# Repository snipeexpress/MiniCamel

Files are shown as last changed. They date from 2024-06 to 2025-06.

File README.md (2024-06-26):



<br/>

The TinyLlama board, assembled
<br/>

This is an expansion of the TinyLlama v2 board created by Eivind Bohler. It combines aspects of the ITX llama as well but in a 100mm x 100mm form factor.

- A fully-fledged 486/Pentium-class PC in a small form factor
- Integrated Sound Blaster Pro-compatible audio using the crystal CS4237b sound chip
- Onboard fan controller for optional CPU or case fan support
- Hard drive clicker and system LED on-board with breakout header for installing in a custom case.
- Support for external OPL3 module from the ITX llama.
- Integrated PCM5102 module
- S/PDIF port for digital audio output
- Ethernet port for 10/100 ethernet capability
- Relocated ESP8266 module for use as dial-up modem emulator or wireless network connectivity.
- Add a Raspberry Pi Zero 2 for Roland MT&#8209;32 and General MIDI music
- Open-source hardware schematics, board layout and BIOS - build your own!

## Table of Contents
- [Summary](#summary)
- [Project Goals](#project-goals)
- [What's New In Version 2?](#whats-new-in-version-2)
- [Full system specs](#full-system-specs-revision-21)
- [Building](#building)
  * [Sourcing Parts](#sourcing-parts)
  * [Assembly](#assembly)
  * [Programming the CH559](#programming-the-ch559)
  * [Programming the BIOS](#programming-the-bios)
  * [Installing DOS](#installing-dos)
  * [Programming the CS4237B Firmware](#programming-the-cs4237b-firmware)
- [MT-32 / General MIDI](#mt-32--general-midi)
- [WiFi Connectivity](#wifi-connectivity)
- [Wiki](#wiki)
- [Help](#help)
- [Roadmap](#roadmap)
- [Contributing](#contributing)
- [License](#license)
- [Contact](#contact)
- [Acknowledgements](#acknowledgments)

<br/>

## Project Goals
I'm learning how to build these types of boards and decided to use a project I've built in the past and that I'm familiar with as a starting point.
The biggest goal I have for this project is to learn enough to begin designing my own circuits. In this case, I am relying on circuits that already exist
but my hope is that my next project will be a scratch-built device that doesn't require any use of pre-existing projects.

<p>
  TinyLlama
</p>

Both the CH559 and the ESP8266 can be easily re-flashed/programmed in-place.  
Look at [Programming the CH559](#programming-the-ch559) and [Programming the ESP8266][wiki-wifi].

## Full system specs (revision 0.1)
### Hardware
- **86Duino System-on-module**
  * Vortex86EX CPU running at 60-500 MHz
  * 16 KB L1 cache (can be disabled)
  * 128 KB L2 cache
  * 128 MB DDR3 RAM
  * 8 MB programmable flash ROM
- **Vortex86VGA module running off a x1 PCI-e lane**
  * Maximum resolution: 1024x768, 60 Hz
  * 4 MB SRAM
  * [Alternative graphics cards][wiki-alternative-gpus]
- **Crystal CS4237B all-in-one audio chip**
- **12mm PC-speaker**
- **12mm HDD clicker speaker**
- **CR1220 battery for persistent real-time clock**
- **Power and reset buttons**
- **Connectivity**
  * USB-C for power
  * 2 x USB Type-A connectors for HID-compliant keyboard and mice
  * 2 x USB Type-A connectors for storage devices (USB 2.0)
  * MicroSD slot for storage
  * DE-9 RS232 serial port (COM1)
  * 1x RJ45 10/100 Ethernet port
  * Modem or Ethernet/SLIP over WiFi (COM2)
  * Internal fan pin-header (5V only)
  * 3.5mm line-out audio jack
  * S/PDIF jack for digital line out
- **mt32-pi subsystem**
  * 40-pin connector for a Raspberry Pi Zero 2
  * Integrated PCM5102 I²S DAC module
  * Button for toggling between MT32 / General MIDI mode
  * Button for switching between audio ROMs / soundbanks
  * 4-pin I²C connector for an OLED display

### Software
- **[Custom Coreboot/SeaBIOS ROM][bios]**
- **MS-DOS / FreeDOS**

<p>
  TinyLlama BIOS
</p>

## Building
### Sourcing Parts
I will post the BOM after I complete the initial test build to make sure everything is correct.

#### For MT-32/MIDI - optional
- Raspberry Pi Zero 2 W with a microSD card
- An [mt32-pi compatible OLED display][mt32-pi-oled], optional but nice

### Programming the CH559
1. Download the latest firmware binary from this repo, in the `hidman-binary` folder. Alternatively, get the latest source code from the [official repo][hidman] and compile it yourself.
2. Download and install `WCHISPTool_Setup.exe` from [WCH's website][wch]. Unfortunately, this tool only supports Windows. If you're on macOS or Linux, maybe try using virtualization software, or even another computer.
3. Open the `WCHISPTool_CH54x-55x` application.
4. Make sure the MiniCamel is powered off.
5. **Remove** the jumper from the "HID_POWER" pin header on the PCB (to ensure that the computer doesn't backpower the MiniCamel).
6. Connect a USB cable (type A to type A) between one of the HID USB ports on the MiniCamel and the Windows computer.
7. Press and hold the "PRG" button on the bottom side of the MiniCamel until the CH559 device pops up in the WCHISPTool.
8. Select the firmware binary file under _Download File -> Object File1_.
9. Click the "Download" button. Hopefully you'll get a success message in the log section on the right side of the program window.
10. Disconnect the USB cable.
11. **Add** the jumper to the "HID_POWER" pin header on the PCB.
12. Connect a keyboard to one of the HID USB ports. You should be good to go!

### Programming the BIOS
When purchasing the SOM-128-EX module from DMP, its ROM chip comes preinstalled with an Arduino-like bootloader which isn't what we want. Also, the  "crossbar" is configured for using the module with the 86Duino Zero/One boards - meaning its default pin layout is completely different from what we need for the MiniCamel.

Follow these steps to flash the ROM with the MiniCamel BIOS for the first time:
1. Find a USB flash drive, must be minimum 32 MB in size (shouldn't be a problem these days). Note that not all USB drives are bootable. Use a well-known bootable drive. _NB: You have to use a USB stick for this, an SD card won't work since the crossbar is configured to use different pins on the SOM for SD traffic._
2. Do a block-level transfer of the `INITBIOS.IMG` from this repo to the USB drive. Use [Balena Etcher][balena-etcher], or the command line if you know what you're doing (macOS example):
```
$ diskutil list
(Find your USB drive, eg. /dev/disk2)
$ diskutil unmountDisk /dev/disk2
$ sudo dd if=INITBIOS.IMG of=/dev/rdisk2 bs=1m
```
3. Insert the USB flash drive into the MiniCamel and turn it on. It'll hopefully boot into MS-DOS. Then, to flash the ROM:
```
C:\>anybios w initbios.rom
```
...and reboot.  

For subsequent BIOS updates, you can use the ROM's built-in virtual floppy drive available from the boot menu (press F12).  
When booted from this you'll only need a regular USB stick (formatted as FAT16/FAT32) containing the new BIOS file.

### Installing MS-DOS
_A note on selecting the DOS type:  
I've gone with MS-DOS 6.22 for maximum compatibility.  
If you prefer FreeDOS (or another DOS variant), prepare a bootable USB installer disk and use that instead of the built-in virtual floppy._
1. Pick a bootable USB drive or Micro SD card to use as the boot drive - for MS-DOS 6.22 you'll be limited to FAT16 and 2 GB per partition (though you can have several). For FreeDOS with FAT32 you can go all the way up to 2 TB.
2. Insert it, turn on the system, press F12 to bring up the boot menu, and select the virtual floppy drive.
3. Use `fdisk` from the command prompt to partition the SD/USB drive and set it to be `Active`.
4. Restart and again select to boot from the virtual floppy.  
Use `format c: /s /u` to format the drive and copy over system files. Finally use `fdisk /mbr` to make sure the Master Boot Record is correct and the drive should be bootable.
5. Copy over the `DOS` folder from A: to C:.  
You can either do this manually and create `CONFIG.SYS` and `AUTOEXEC.BAT` files to your liking, or more conveniently, just run the `SETUP.BAT` script that'll do this for you. The provided config files lets you choose from a clean boot or a QEMM-based one with XMS, EMS and 631 kB of free conventional memory.

### Programming the CS4237B Firmware
1. Copy the `CS4237B` and `UNISOUND` folders from this GitHub repo over to your SD/USB boot drive and start the system.
2. To program the firmware, run the `RESOURCE.EXE` command below and check that you get the same output:
```
C:\>cd cs4237b
C:\CS4237B>resource /f=0x120 /r=cs4237b.asm /e

Reading data from CS4237B.ASM
Length = 292    Programming EEPROM Block: 1 2    EEPROM programmed

Verifying EEPROM:
Verifying CS4237B.ASM against EEPROM . . .      Verified OKAY
```
3. Make sure the correct `BLASTER` environment variable is set and `UNISOUND.COM` command is called from `AUTOEXEC.BAT`. Note that the 8-bit DMA channel is **1** and the IRQ is **7**:
```
SET BLASTER=A220 I7 D1 P330 T4
C:\UNISOUND\UNISOUND.EXE /V60 /VW60 /VF60 /VL60 /VP60 /VC0 /VM0
```
4. Reboot the system, and you should get the following output:
```
Universal ISA PnP Sound Card Driver for DOS v0.76f. (c) JazeFox 2019-21
-----------------------------------------------------------------------
PnP card found: [CSC7537] CS4237B
BLASTER environment var found! Loading settings...
ADD:220 WSS:534 OPL:388 IRQ:7 DMA:1/1 MPU:330/I9 CTR:120 JOY:200
Initialization done.
Crystal Mixer [VOL:85 WAV:80 FM:80 LIN:0 CD:0 MIC:0]
```
5. Feel free to experiment with the different volume levels, look at the `C:\UNISOUND\UNISOUND.TXT` file for further guidance.
6. Fire up a few games to test that Adlib, SoundBlaster FM and digital sound effects are working properly.

## MT-32 / General MIDI
If you've installed [mt32-pi][mt32-pi] on a Raspberry Pi Zero 2 and connected it to the TinyLlama, it should be ready to go using IO port 330. Use the third button from the left (labeled "SYNTH_SW" on the PCB) to switch between MT-32 and General MIDI mode.  
If you want to play old games that require "MPU-401 Intelligent Mode" (Sierra games, Monkey Island 1, etc), try running [SoftMPU][softmpu]:
```
C:\SOFTMPU\>softmpu /mpu:330 /sb:220 /irq:7
```
If you want to hook up an I²C OLED display to the mt32-pi, there's a pin header on the MiniCamel labeled "I2C_OLED". The order of the pins from 1 to 4 is: GND, VCC, SCL, SDA with pin 1 being the one closest to the 3.5mm audio jack.

## WiFi Connectivity
There's a [section][wiki-wifi] in the wiki dedicated to this, take a look.

## Wiki
For an in-depth discussion of the various components, installation, configuration, etc, take a look at the [wiki][wiki].

## Help
This project is indended for people with a fair bit of hardware- and DOS knowledge. If you have questions or need help, please look at the [wiki][wiki] and [FAQ][wiki-faq] section first.

## License
[GNU General Public License v3.0](LICENSE)

## Acknowledgements

Many thanks to

- [Eivind Bohler] for creating the initial project, helping me troubleshoot my ITX llama and being a HUGE inspiration.
- [Rasteri][rasteri-videos] for creating the WeeCee and Wee86 that got me interested in going down this rabbit hole.
- [The Vogons forum][vogons] for being a great resource and always providing help when needed.
- [86Duino / DMP][86duino] for making a great and affordable system-on-module. (I concur with Eivind on this!)

[tinyllama1]: https://github.com/eivindbohler/tinyllama
[hidman]: https://github.com/rasteri/HIDman
[wiki-alternative-gpus]: https://github.com/eivindbohler/tinyllama2/wiki/alternative-gpus
[bios]: https://github.com/eivindbohler/tinyllama2-bios

[wiki]: https://github.com/eivindbohler/tinyllama2/wiki
[wiki-assembly]: https://github.com/eivindbohler/tinyllama2/wiki/assembly
[wiki-bom]: https://github.com/eivindbohler/tinyllama2/wiki/bom
[wiki-faq]: https://github.com/eivindbohler/tinyllama2/wiki/faq
[wiki-wifi]: https://github.com/eivindbohler/tinyllama2/wiki/wifi-connectivity

[balena-etcher]: https://www.balena.io/etcher
[mt32-pi-oled]: https://github.com/dwhinham/mt32-pi/wiki/LCD-and-OLED-display
[wch]: http://www.wch-ic.com/products/CH559.html

[issues]: https://github.com/eivindbohler/tinyllama2/issues

[rasteri-videos]: https://www.youtube.com/user/TheRasteri/videos
[vogons]: https://www.vogons.org
[86duino]: https://www.86duino.com
[mt32-pi]: https://github.com/dwhinham/mt32-pi
[softmpu]: http://bjt42.github.io/softmpu

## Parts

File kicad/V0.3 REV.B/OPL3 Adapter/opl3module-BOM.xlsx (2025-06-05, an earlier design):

Comment | Designator | Footprint | LCSC
0.1uF | C1,C2,C3,C4,C9,C10,C11,C12,C17,C18,C19,C20,C25,C26,C27,C28,C33,C34,C35,C36,C41,C42,C43,C44 | C_0402_1005Metric | C1525
68pF | C5,C13,C21,C29,C37,C45 | C_0402_1005Metric | C76977
2.7nF | C6,C7,C14,C15,C22,C23,C30,C31,C38,C39,C46,C47 | C_0603_1608Metric | C1625600
10uF | C8,C16,C24,C32,C40,C48 | C_0603_1608Metric | C344022
600Ω@100MHz | FB1,FB2,FB3,FB4,FB5,FB6 | R_0402_1005Metric | C160977
EXT_SYNTH | J1,J2,J3,J4,J5,J6 | P_CONN_02X10 | C492427
33 | R1,R6,R11,R16,R21,R26 | R_0402_1005Metric | C138002
6.8k | R2,R3,R7,R8,R12,R13,R17,R18,R22,R23,R27,R28 | R_0402_1005Metric | C93940
8.2k | R4,R5,R9,R10,R14,R15,R19,R20,R24,R25,R29,R30 | R_0402_1005Metric | C138071
TL074 | U3,U6,U9,U12,U15,U18 | U_TSSOP-14_4.4x5mm_P0.65mm | C6964
14.318MHz | XO1,XO2,XO3,XO4,XO5,XO6 | XO_SMD5032 | C387230

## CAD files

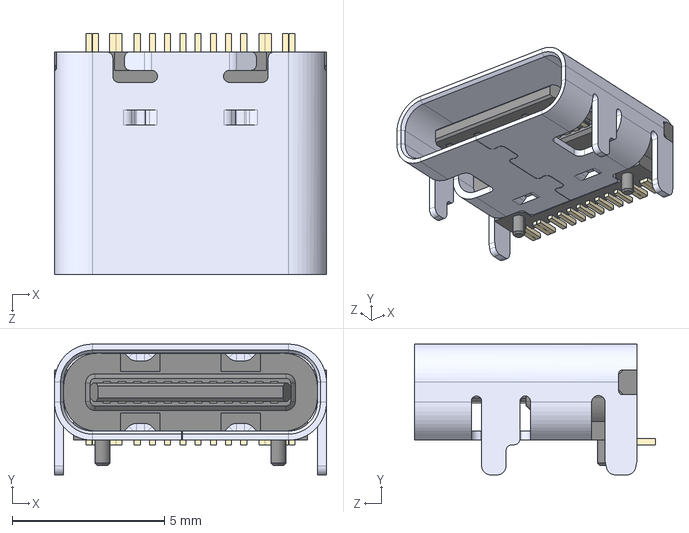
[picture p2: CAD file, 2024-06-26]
3dmodels/TYPE-C-31-M-12--3DModel-STEP-56544.STEP
8.94 x 4.30 x 7.90 mm

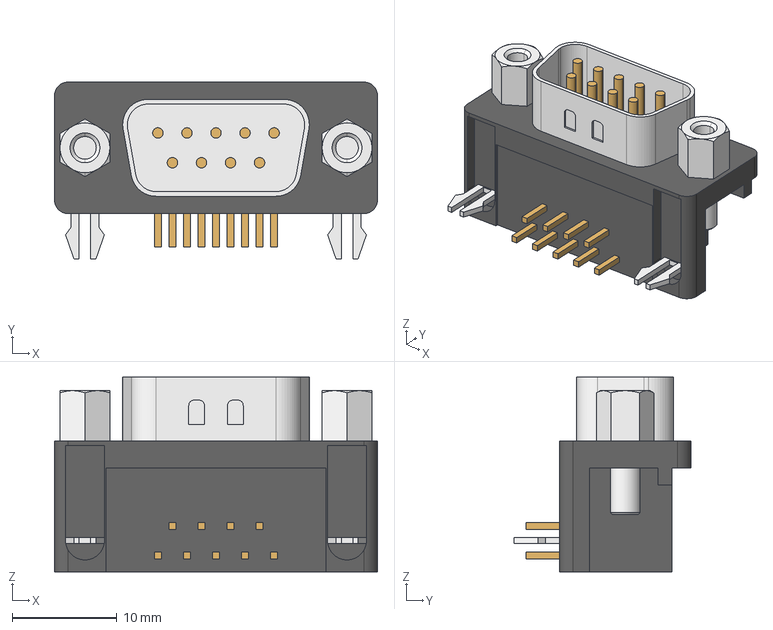
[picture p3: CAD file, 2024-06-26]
kicad/V0.1/3dmodels/connector_a-ds_09_a_kg-t2.step
30.8 x 16.9 x 18.6 mm

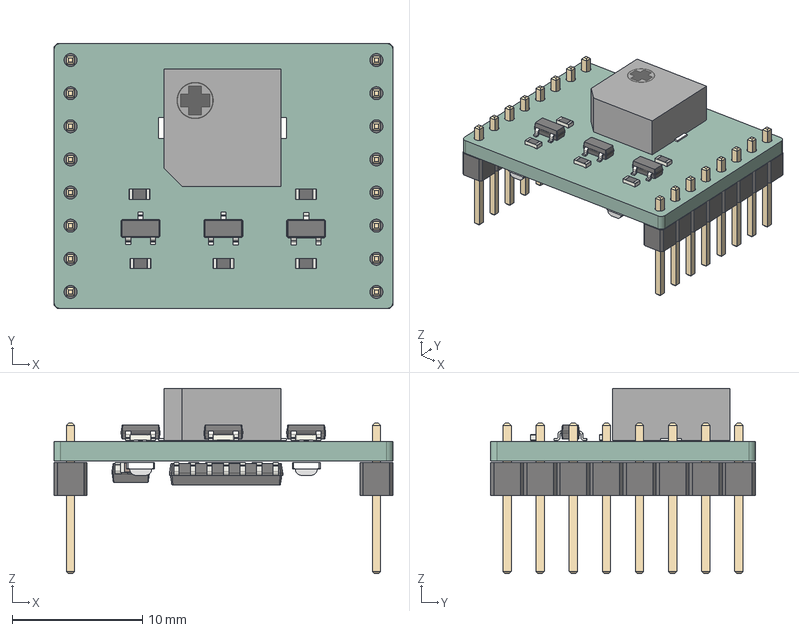
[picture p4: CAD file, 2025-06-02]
kicad/V1.01 REV.B/Riser/PCB_3D_riser.STEP
26.0 x 20.3 x 14.2 mm
R_0603_1608Metric x 7
SMT-0927-S-12-R
SOT-23 x 3
PinHeader_1x08_P2.54mm_Vertical x 2
C_0603_1608Metric x 5
LTST-S220KSKT x 2
SOT-23-5
D_SOD-323F
SOIC-14_3.9x8.7mm_P1.27mm
MiniCamel_riser_PCB

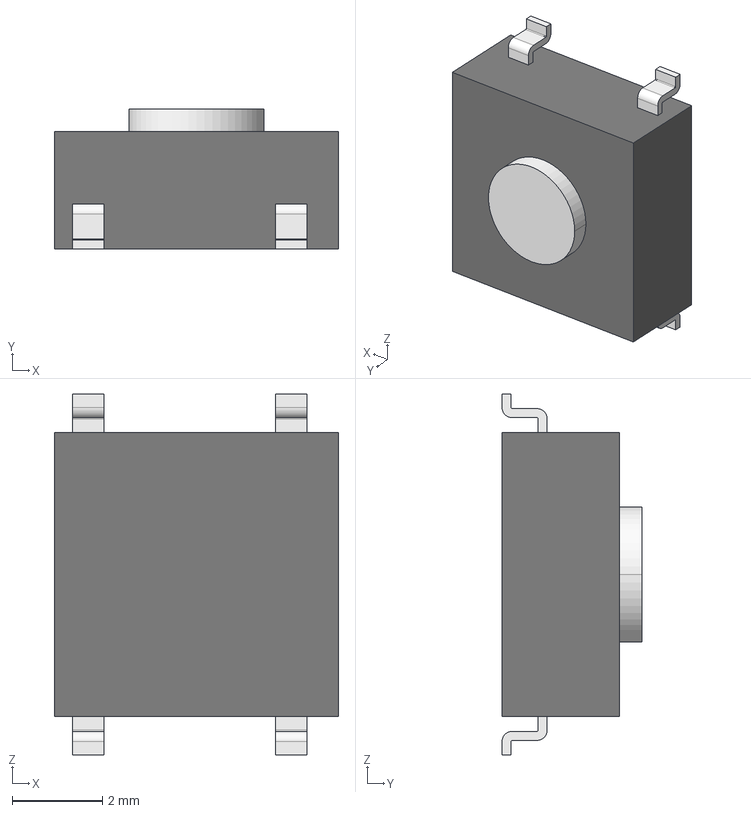
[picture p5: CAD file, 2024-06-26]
3dmodels/b3fs-1000p.stp
6.30 x 3.10 x 8.00 mm

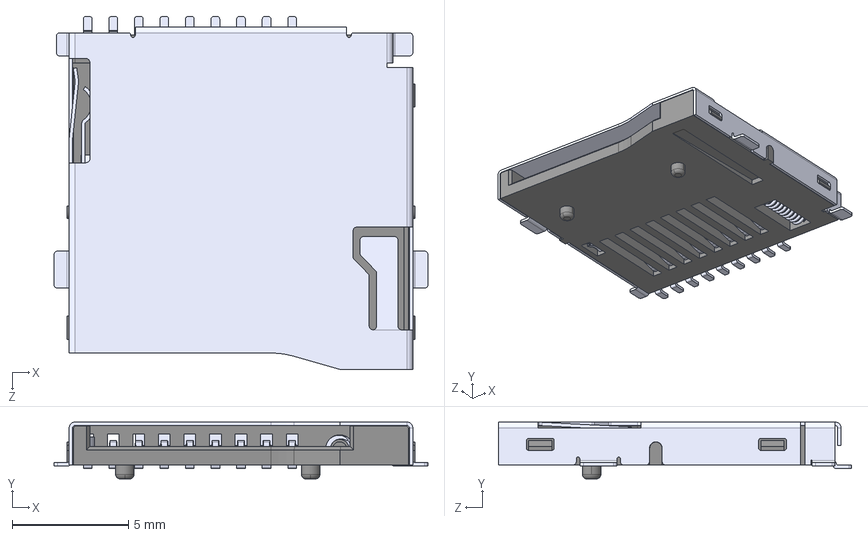
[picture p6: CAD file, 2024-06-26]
kicad/V0.1/3dmodels/TF-01A--3DModel-STEP-56544.STEP
16.1 x 2.45 x 15.2 mm

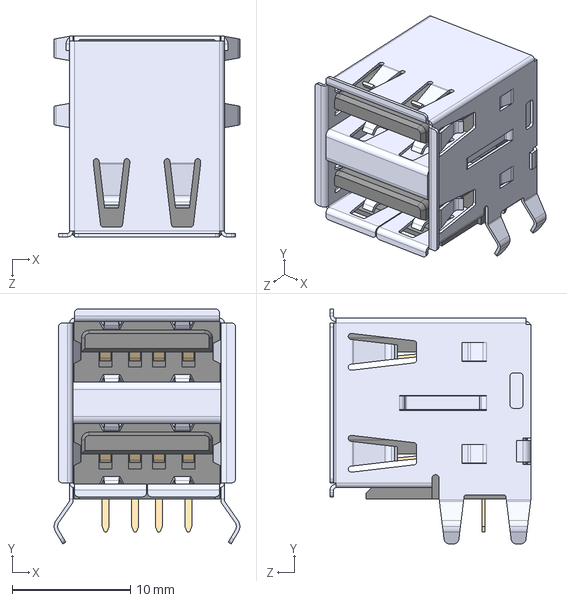
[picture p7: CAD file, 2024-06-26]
3dmodels/USB1035-GF-P-0-B-B--3DModel-STEP-269445.STEP
15.7 x 19.9 x 17.0 mm

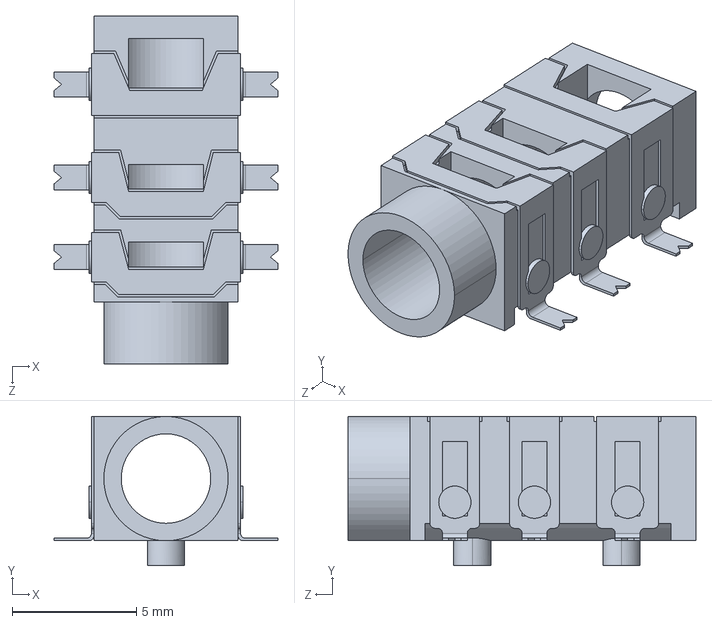
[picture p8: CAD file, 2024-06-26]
kicad/V0.1/3dmodels/JackPJ313D.STEP
9.00 x 6.00 x 14.0 mm

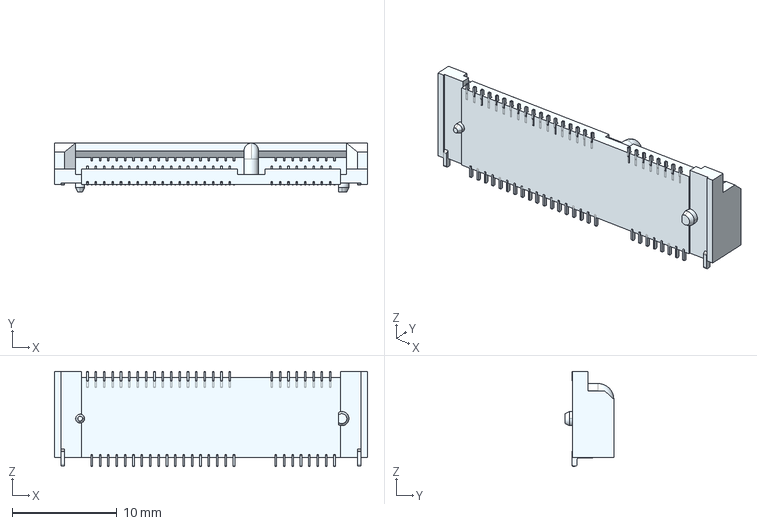
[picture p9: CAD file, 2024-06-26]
3dmodels/2041119-1.stp
29.9 x 4.65 x 9.09 mm

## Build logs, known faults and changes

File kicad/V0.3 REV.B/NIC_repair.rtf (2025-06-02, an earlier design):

Remove c1 and bridge
Replace R2 and R3 with 100nF capacitors
Remove R4 and R5
Cut connection between 4,5 and 7,8 (leave floating)

Change
C45 to 1uF
C47 to 1uF

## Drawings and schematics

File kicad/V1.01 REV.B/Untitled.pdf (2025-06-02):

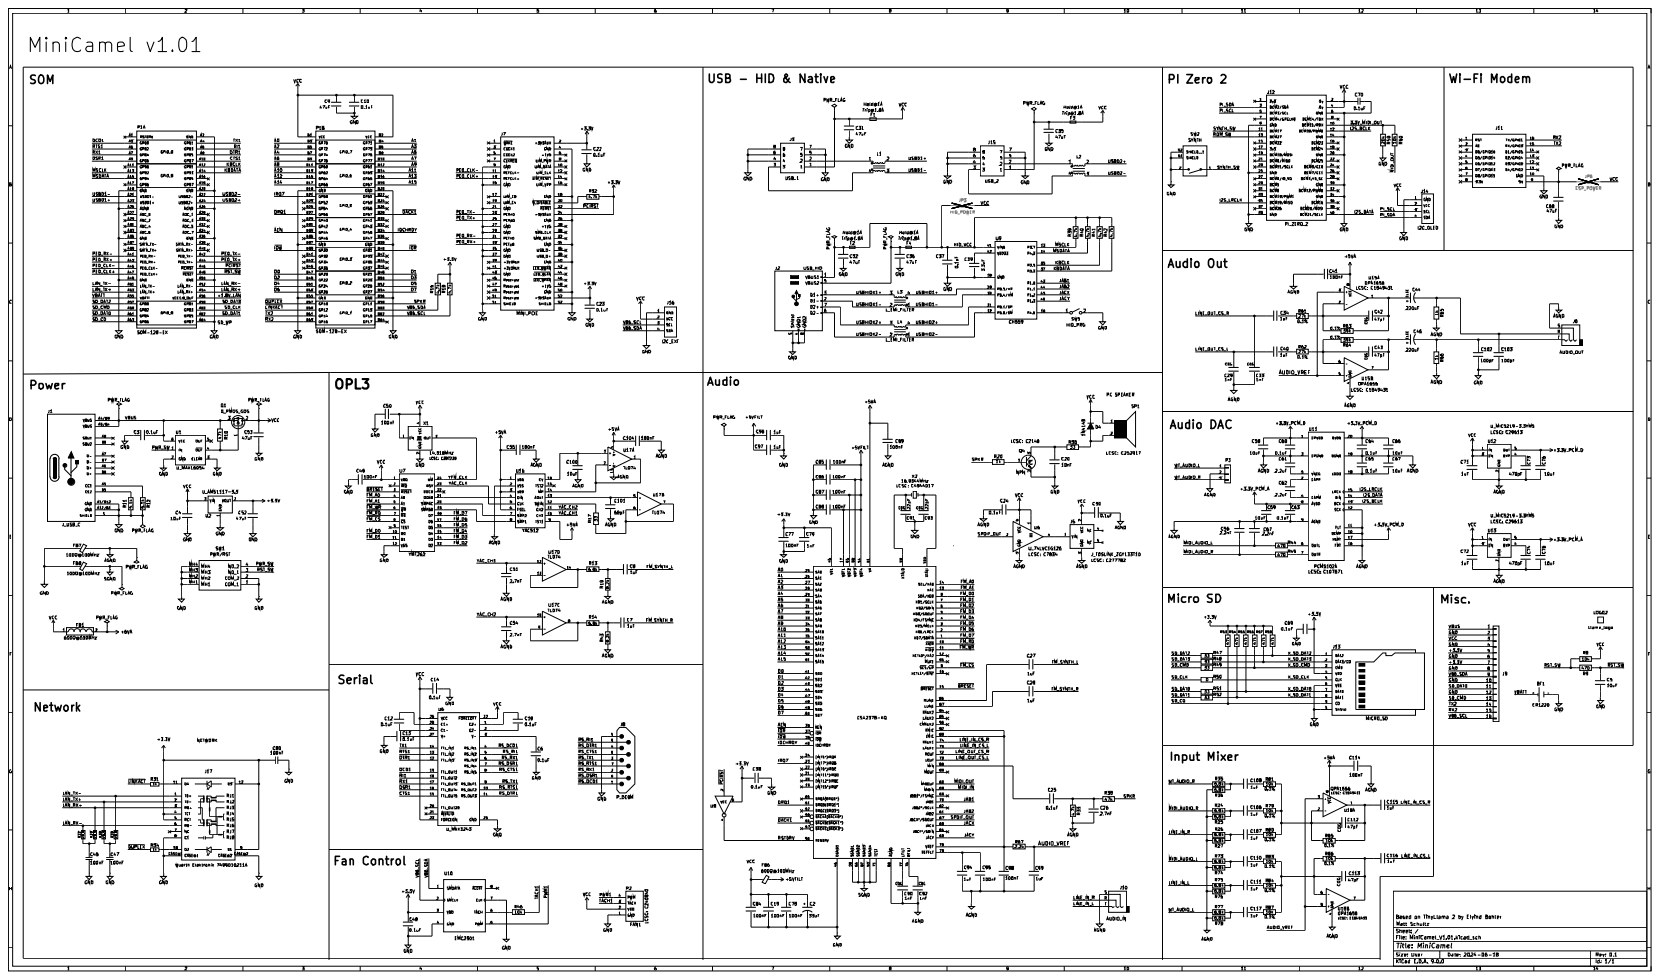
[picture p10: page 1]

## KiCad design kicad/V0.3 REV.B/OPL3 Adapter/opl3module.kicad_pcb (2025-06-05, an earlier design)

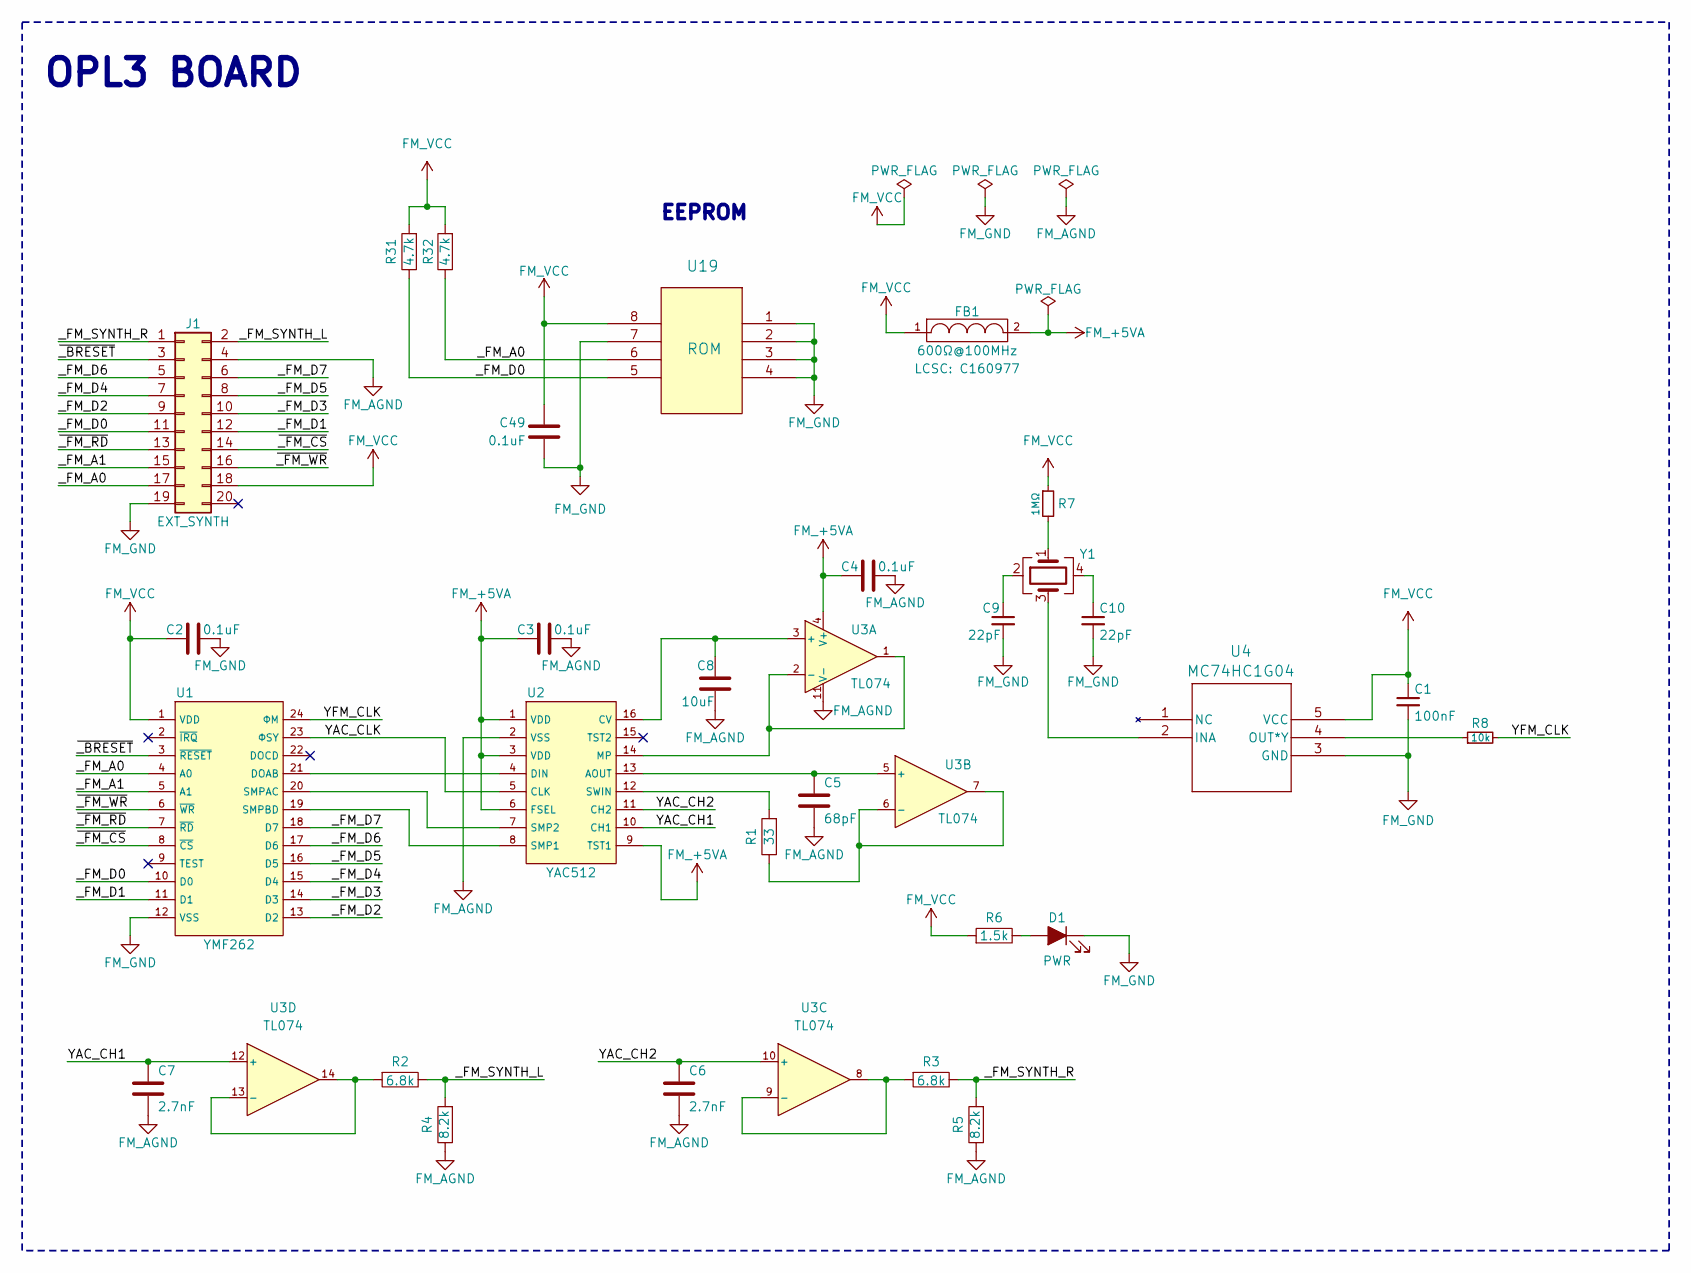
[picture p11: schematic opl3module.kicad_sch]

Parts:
C1: 100nF; C_0402_1005Metric
C2, C3, C4, C49: 0.1uF; C_0402_1005Metric_no_outline
C5: 68pF; C_0402_1005Metric_no_outline
C6, C7: 2.7nF; C_0603_1608Metric_no_outline
C8: 10uF; C_0603_1608Metric_no_outline
C9, C10: 22pF; C_0402_1005Metric
D1: PWR; D_0603_1608Metric; LCSC C130723
FB1: 600Ω@100MHz; R_0402_1005Metric_no_outline; LCSC C160977
J1: EXT_SYNTH; P_CONN_02X10
R1: 33; R_0402_1005Metric_no_outline
R2, R3: 6.8k; R_0402_1005Metric_no_outline
R4, R5: 8.2k; R_0402_1005Metric_no_outline
R6: 1.5k; R_0603_1608Metric_no_outline; LCSC C25117
R7: 1MΩ; R_0603_1608Metric
R8: 10k; R_0603_1608Metric
R31, R32: 4.7k; R_0402_1005Metric_no_outline
U1: YMF262; SOP-24_7.5x15.4mm_P1.27mm
U2: YAC512; SOP-16_4.4x10.4mm_P1.27mm
U3: TL074; SOIC-14_3.9x8.7mm_P1.27mm
U4: MC74HC1G04; SC70-5_ONS
U19: ROM; SOIC8-N_MC_MCH
Y1: Crystal_GND24; Crystal_SMD_5032-4Pin_5.0x3.2mm

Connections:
/YAC_CH1: C7.1, U2.10 (CH1), U3.12 (+)
/YAC_CH2: C6.1, U2.11 (CH2), U3.10 (+)
/YAC_CLK: U1.23 (ΦSY), U2.5 (CLK)
/YFM_CLK: R8.2, U1.24 (ΦM)
/_FM_A0: J1.17, R32.1, U1.4 (A0), U19.6
/_FM_A1: J1.15, U1.5 (A1)
/_FM_D0: J1.11, R31.1, U1.10 (D0), U19.5
/_FM_D1: J1.12, U1.11 (D1)
/_FM_D2: J1.9, U1.13 (D2)
/_FM_D3: J1.10, U1.14 (D3)
/_FM_D4: J1.7, U1.15 (D4)
/_FM_D5: J1.8, U1.16 (D5)
/_FM_D6: J1.5, U1.17 (D6)
/_FM_D7: J1.6, U1.18 (D7)
/_FM_SYNTH_L: J1.2, R2.1, R4.2
/_FM_SYNTH_R: J1.1, R3.1, R5.2
/~_BRESET: J1.3, U1.3 (~RESET)
/~_FM_CS: J1.14, U1.8 (~CS)
/~_FM_RD: J1.13, U1.7 (~RD)
/~_FM_WR: J1.16, U1.6 (~WR)
FM_+5VA: C3.2, C4.2, FB1.2, U2.1 (VDD), U2.3 (VDD), U2.6 (FSEL), U2.9 (TST1), U3.4 (V+)
FM_AGND: C3.1, C4.1, C5.2, C6.2, C7.2, C8.1, J1.4, R4.1, R5.1, U2.2 (VSS), U3.11 (V-)
FM_GND: C1.2, C2.1, C9.2, C10.2, C49.2, D1.1 (K), J1.19, U1.12 (VSS), U4.3 (GND), U19.1, U19.2, U19.3, U19.4, U19.7
FM_VCC: C1.1, C2.2, C49.1, FB1.1, J1.18, R6.2, R7.1, R31.2, R32.2, U1.1 (VDD), U4.5 (VCC), U19.8
unnamed: C9.1, Y1.2
unnamed: C10.1, Y1.4
unnamed: D1.2 (A), R6.1
unnamed: R7.2, Y1.1
unnamed: U1.21 (DOAB), U2.4 (DIN)
unnamed: U1.20 (SMPAC), U2.7 (SMP2)
unnamed: U1.19 (SMPBD), U2.8 (SMP1)
unnamed: C5.1, U2.13 (AOUT), U3.5 (+)
unnamed: C8.2, U2.16 (CV), U3.3 (+)
unnamed: U2.14 (MP), U3.1, U3.2 (-)
unnamed: R1.2, U2.12 (SWIN)
unnamed: R1.1, U3.6 (-), U3.7
unnamed: R3.2, U3.8, U3.9 (-)
unnamed: R2.2, U3.13 (-), U3.14
unnamed: U4.2 (INA), Y1.3
unnamed: R8.1, U4.4 (OUT*Y)

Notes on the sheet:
OPL3 BOARD
EEPROM

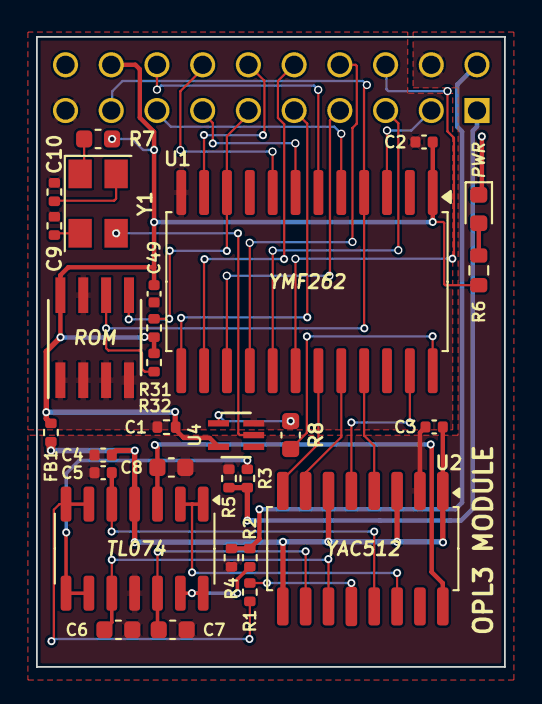
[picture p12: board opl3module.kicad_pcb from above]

Board: 4 copper layers, 26.0 x 35.0 mm, 30 parts (1 on the bottom side), 40 nets.

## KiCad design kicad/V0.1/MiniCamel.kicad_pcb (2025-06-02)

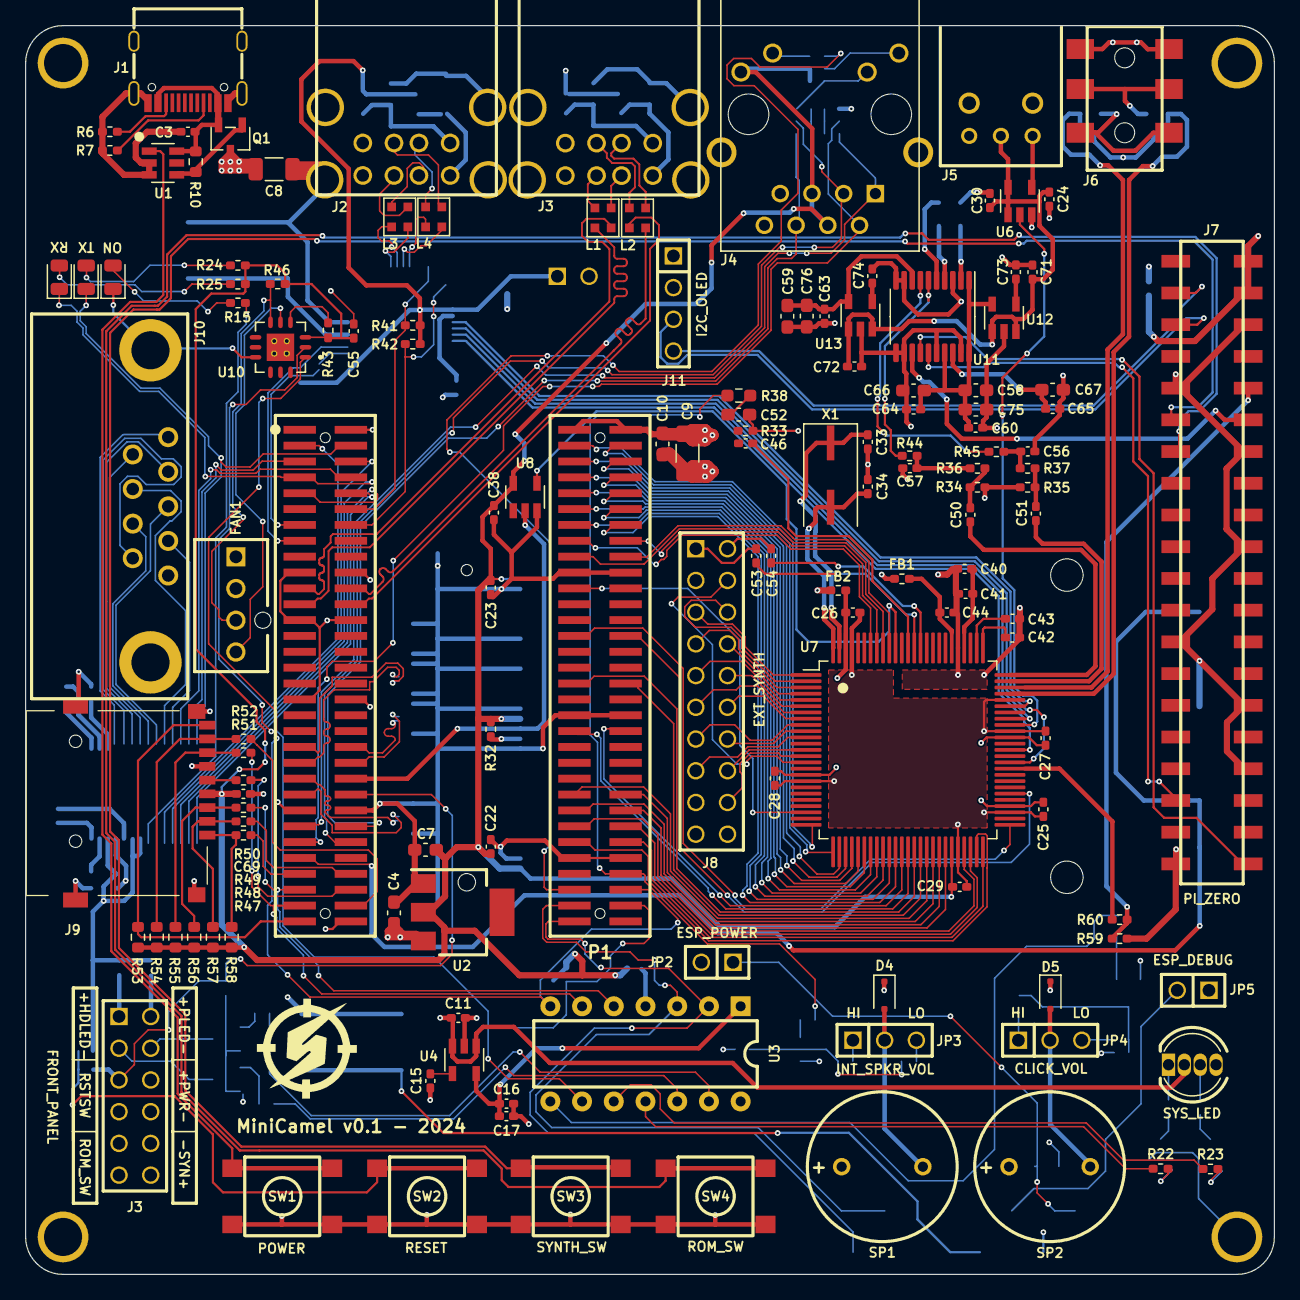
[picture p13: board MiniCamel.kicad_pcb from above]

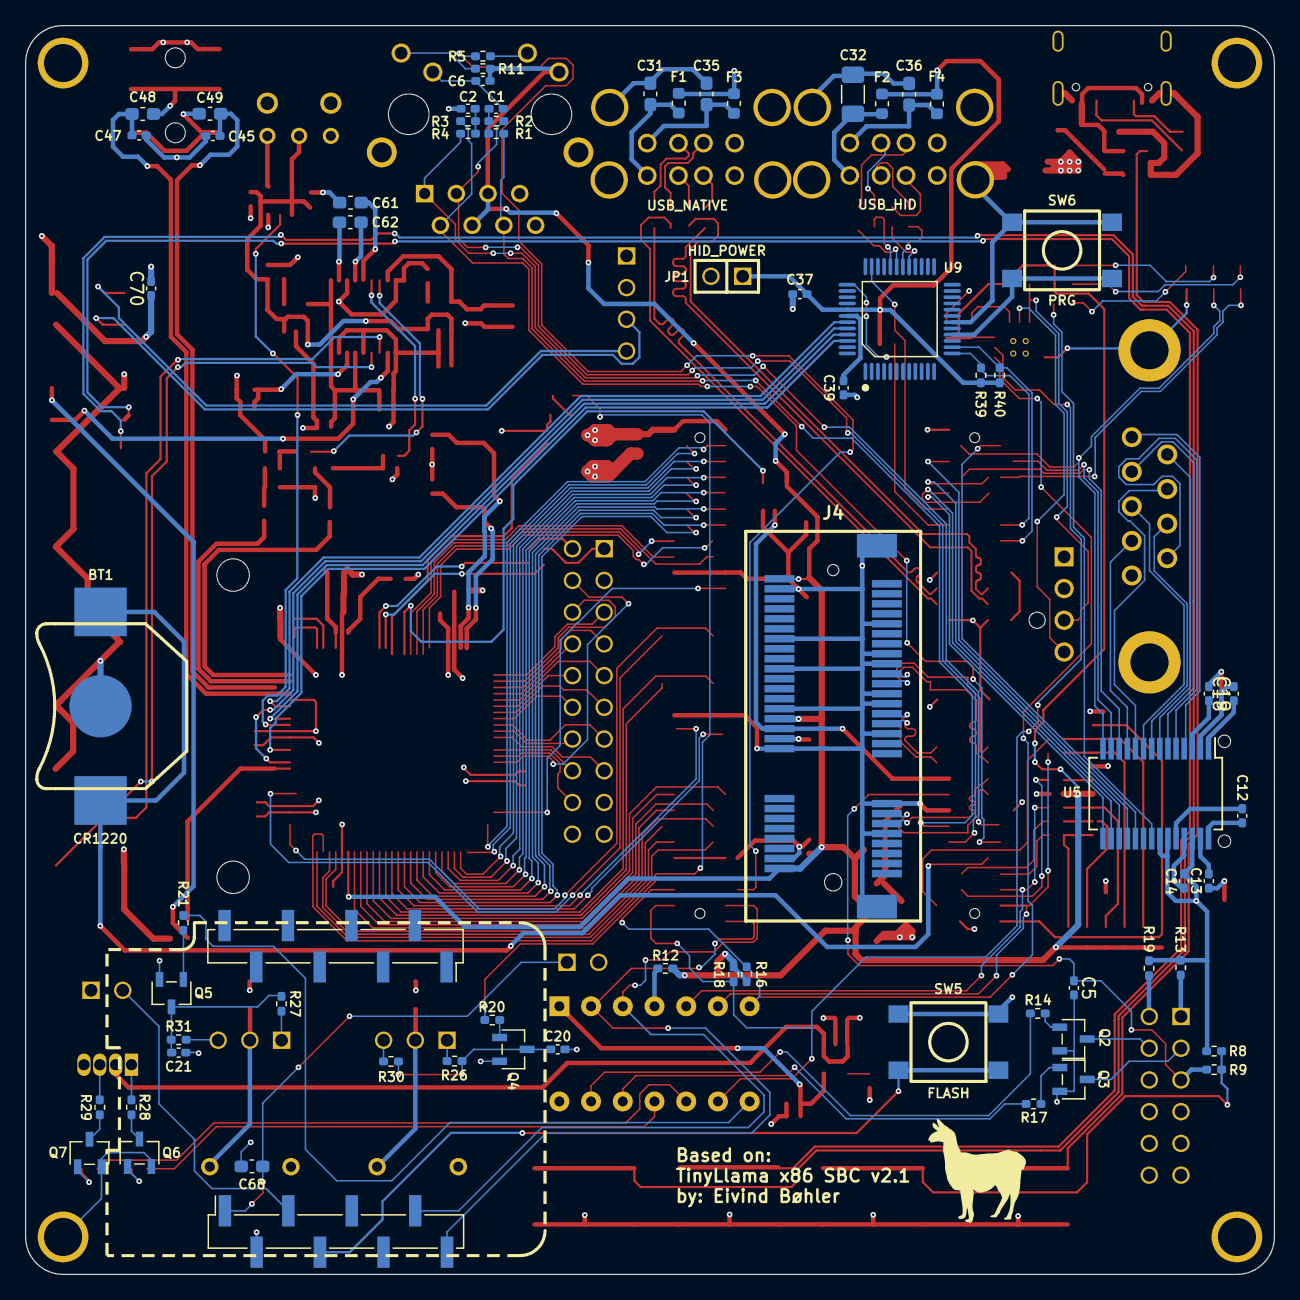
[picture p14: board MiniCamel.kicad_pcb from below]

Board: 4 copper layers, 100.0 x 100.0 mm, 209 parts (69 on the bottom side), 229 nets.

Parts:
BT1: CR1220; BT_MY-1220-03
C1, C2, C3, C6, C12, C13, C14, C17, C18, C19, C22, C23, C24, C25, C26, C27, C28, C29, C30, C37, C38, C41, C44, C46, C55, C60, C63, C64, C65, C69, C70: 0.1uF; C_0402_1005Metric_Pad0.74x0.62mm_HandSolder
C4, C48, C49, C58, C59, C66, C67, C75, C76: 10uF; C_0603_1608Metric_Pad1.08x0.95mm_HandSolder
C5, C16, C50, C51: 10uF; C_0402_1005Metric_Pad0.74x0.62mm_HandSolder
C7, C31, C35, C36, C68: 47uF; C_0603_1608Metric_Pad1.08x0.95mm_HandSolder
C8: 47uF; C_1206_3216Metric
C9, C32: 47uF; C_1206_3216Metric_Pad1.33x1.80mm_HandSolder
C10: 0.1uF; C_0603_1608Metric_Pad1.08x0.95mm_HandSolder
C11, C40, C53, C54, C71, C72: 1uF; C_0402_1005Metric_Pad0.74x0.62mm_HandSolder
C15, C73, C74: 470pF; C_0402_1005Metric_Pad0.74x0.62mm_HandSolder
C20, C21: 10nF; C_0402_1005Metric_Pad0.74x0.62mm_HandSolder
C33, C34: 22pF; C_0402_1005Metric_Pad0.74x0.62mm_HandSolder
C39: 3.3uF; C_0402_1005Metric_Pad0.74x0.62mm_HandSolder
C42, C43, C45, C47: 1nF; C_0402_1005Metric_Pad0.74x0.62mm_HandSolder
C52: 2.7nF; C_0603_1608Metric_Pad1.08x0.95mm_HandSolder
C56, C57: 2.2nF; C_0402_1005Metric_Pad0.74x0.62mm_HandSolder
C61, C62: 2.2uF; C_0603_1608Metric_Pad1.08x0.95mm_HandSolder
D1: CONN; D_0805_2012Metric
D2: TX; D_0805_2012Metric
D3: RX; D_0805_2012Metric
D4, D5: 1N4148; D_SOD-323F
D6: SYS_LED; D_LED_D5.0mm-4_RGB
F1, F2, F3, F4: F; Fuse_0603_1608Metric
FB1, FB2: FB; R_0402_1005Metric_Pad0.72x0.64mm_HandSolder
H1, H2, H3, H4: H_HOLE; H_440_HOLE
J1: J_USB_C; J_USB_TYPE-C-31-M-12
J2: USB_HID; J_USB_A_C12049
J3: USB_NATIVE; J_USB_A_C12049
J3#2: FRONT_PANEL; P_CONN_PANEL
J4: Wuerth Elektronik 7499010211A; 7499010211A
J4#2: J_MINI_PCIE
J5: J_TOSLINK_ZGY133T10
J6: AudioJack3; J_AUDIO35_C95463
J7: PI_ZERO; J_CONN_RPI_SMD
J8: EXT_SYNTH; J_CONN_02X10
J9: MICRO_SD; J_MicroSD_TF01A
J10: P_DE9M
J11: I2C_OLED; P_CONN_01X04_SQUARE
J12: J_WEMOS_D1_MINI
JP1: HID_POWER; P_CONN_01X02_SQUARE
JP2: ESP_POWER; P_CONN_01X02_SQUARE
JP3: INT_SPKR_VOL; P_CONN_01X03_SQUARE
JP4: CLICK_VOL; P_CONN_01X03_SQUARE
JP5: ESP_DEBUG; P_CONN_01X02_SQUARE
L1, L2, L3, L4: L_EMI_FILTER; L_EMI_FILTER_MCM2012B900GBE
LOGO1: snipe_logo; snipe_96x96px
LOGO2: Llama_logo; LLAMA_LOGO
P1: P_SOM-128-EX; P_CONN_SOM-128-EX
P3: FAN1; J_MOLEX_47053-1000
Q1: Q_PMOS_GDS; Q_PFET_ENH_SOT-23-3
Q2, Q3, Q4, Q5, Q6, Q7: NPN; Q_BJT_SOT-23-3
R1, R2, R3, R4: 49.9; R_0402_1005Metric_Pad0.72x0.64mm_HandSolder
R5, R11, R20, R21, R24, R25: 1k; R_0402_1005Metric_Pad0.72x0.64mm_HandSolder
R6, R7: 5.1k; R_0402_1005Metric_Pad0.72x0.64mm_HandSolder
R8, R12, R14, R17, R22, R23, R46, R60: 10k; R_0402_1005Metric_Pad0.72x0.64mm_HandSolder
R9, R44, R45: 470; R_0402_1005Metric_Pad0.72x0.64mm_HandSolder
R10, R53, R54, R55, R56, R57, R58: 47k; R_0603_1608Metric
R13, R19: 330; R_0402_1005Metric_Pad0.72x0.64mm_HandSolder
R15: 1.5k; R_0402_1005Metric_Pad0.72x0.64mm_HandSolder
R16, R18, R32, R33, R39, R40, R41, R42, R43: 4.7k; R_0402_1005Metric_Pad0.72x0.64mm_HandSolder
R26, R27: 200; R_0402_1005Metric_Pad0.72x0.64mm_HandSolder
R28: 600; R_0402_1005Metric_Pad0.72x0.64mm_HandSolder
R29: 2k; R_0402_1005Metric_Pad0.72x0.64mm_HandSolder
R30, R31, R47, R48, R49, R51, R52: 33; R_0402_1005Metric_Pad0.72x0.64mm_HandSolder
R34, R35, R36, R37: 6.8k; R_0402_1005Metric_Pad0.72x0.64mm_HandSolder
R38: 47k; R_0603_1608Metric_Pad0.98x0.95mm_HandSolder
R50: 0; R_0402_1005Metric_Pad0.72x0.64mm_HandSolder
R59: 20k; R_0402_1005Metric_Pad0.72x0.64mm_HandSolder
SP1, SP2: SPEAKER; SP
SW1: POWER; SW_B3FS-1010
SW2: RESET; SW_B3FS-1010
SW3: SYNTH_SW; SW_B3FS-1010
SW4: ROM_SW; SW_B3FS-1010
SW5: FLASH; SW_B3FS-1010
SW6: PRG; SW_B3FS-1010
U1: U_MAX16054; U_TSOT-23-6
U2: U_AMS1117-3.3; U_SOT-223-3_NOTAB
U3: U_ATTINY84A; U_DIP-14_W7.62mm
U4, U12, U13: U_MIC5219-3.3YM5; U_SOT-23-5
U5: U_MAX3243; U_SSOP-28_5.3x10.2mm_P0.65mm
U6: U_74LVC1G126; U_SOT-23-5
U7: CS4237B-KQ; U_TQFP-100_14x14mm_P0.5mm_HandSoldering
U8: U_74LVC1G04; U_SOT-23-5
U9: U_CH559L; U_QFP-12x12_14x14_Pitch0.5mm
U10: EMC2303; U_EMC2303
U11: PCM5102A; U_TSSOP-20_4.4x6.5mm_P0.65mm
X1: 16.9344MHz; X_Crystal_SMD_HC49S-MINI

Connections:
+3.3V: C6.1, C7.1, C22.1, C23.1, C29.2, C38.1, C55.1, C69.1, J4.4 (TCT), J4.5 (RCT), J4.12 (D3), J4#2.2 (+3V3AUX), J4#2.24 (+3V3AUX), J4#2.52 (+3V3AUX), J9.4 (VDD), R11.1, R12.2, R16.2, R18.2, R24.1, R25.1, R32.2, R43.2, R46.1, R53.1, R54.1, R55.1, R56.1, R57.1, R58.1, U2.2 (VOUT), U7.45 (VD1), U8.5 (VCC), U10.3 (VDD)
+3.3VSB: C16.1, C17.2, U3.1 (VCC), U4.5 (OUT)
+3.3V_PCM_A: C59.1, C63.1, C76.1, U11.8 (AVDD), U13.5 (OUT)
+3.3V_PCM_D: C58.1, C60.1, C64.1, C66.1, C75.1, U11.1 (CPVDD), U11.17 (XSMT), U11.20 (DVDD), U12.5 (OUT)
+5VA: C44.1, FB1.2, U7.81 (VA)
+5VFILT: C25.2, C26.2, C27.2, C28.2, FB2.2, U7.17 (VDF1), U7.54 (VDF4), U7.65 (VDF2), U7.98 (VDF3)
/3.3V_MIDI_OUT: J7.10 (BCM15/RDX), R59.1, R60.2
/A0: P1.B3 (GP70), U7.25 (SA0)
/A1: P1.B4 (GP71), U7.26 (SA1)
/A2: P1.B5 (GP72), U7.27 (SA2)
/A3: P1.B6 (GP73), U7.28 (SA3)
/A4: P1.B7 (GP74), U7.29 (SA4)
/A5: P1.B8 (GP75), U7.30 (SA5)
/A6: P1.B9 (GP76), U7.31 (SA6)
/A7: P1.B10 (GP77), U7.32 (SA7)
/A8: P1.B11 (GP60), U7.33 (SA8)
/A9: P1.B12 (GP61), U7.34 (SA9)
/A10: P1.B13 (GP62), U7.35 (SA10)
/A11: P1.B14 (GP63), U7.36 (SA11)
/A12: P1.B15 (GP64), U7.94 (SA12)
/A13: P1.B16 (GP65), U7.93 (SA13)
/A14: P1.B17 (GP66), U7.92 (SA14)
/A15: P1.B18 (GP67), U7.91 (SA15)
/AEN: P1.B33 (GP44), U7.39 (AEN)
/CTS1: P1.A10 (GP07), U5.15 (TTL_OUT5)
/D0: P1.B47 (GP20), U7.41 (SD0)
/D1: P1.B48 (GP21), U7.42 (SD1)
/D2: P1.B49 (GP22), U7.43 (SD2)
/D3: P1.B50 (GP23), U7.44 (SD3)
/D4: P1.B51 (GP24), U7.47 (SD4)
/D5: P1.B52 (GP25), U7.48 (SD5)
/D6: P1.B53 (GP26), U7.49 (SD6)
/D7: P1.B54 (GP27), U7.50 (SD7)
/DCD1: P1.A3 (GP00), U5.19 (TTL_OUT1)
/DCD2: J12.11 (D4/GPIO2), JP5.2
/DRQ1: P1.B27 (GP56), U7.51 (DRQB(DRQ1*))
/DSR1: P1.A9 (GP06), U5.16 (TTL_OUT4)
/DTR1: P1.A8 (GP05), U5.12 (TTL_IN3)
/FM_A0: J8.18, U7.14 (SCL/XA0)
/FM_A1: J8.16, U7.13 (XA1)
/FM_D0: J8.12, U7.8 (SDA/XD0)
/FM_D1: J8.11, U7.7 (XD1/SCLK)
/FM_D2: J8.10, U7.6 (XD2/SDIN)
/FM_D3: J8.9, U7.5 (XD3/SDOUT)
/FM_D4: J8.8, U7.4 (XD4/FSYNC)
/FM_D5: J8.7, U7.3 (XD5/MCLK)
/FM_D6: J8.6, U7.2 (XD6/LRCK)
/FM_D7: J8.5, U7.1 (XD7/SDATA)
/FM_SYNTH_L: C53.2, J8.1
/FM_SYNTH_R: C54.2, J8.2
/HDD_LED+: J3#2.1, R13.2
/HDD_LED-: J3#2.2, Q3.3 (C)
/HID_VCC: C37.2, F2.1, F4.1, JP1.1, R39.2, R40.2, R41.2, R42.2, U9.41 (VIN5)
/I2S_BCLK: J7.12 (BCM18/PWM0), U11.13 (BCK)
/I2S_DATA: J7.40 (BCM21/SCLK), U11.14 (DIN)
/I2S_LRCLK: J7.35 (BCM19/MISO), U11.15 (LRCK)
/IOCHRDY: P1.B34 (GP45), U7.40 (IOCHRDY)
/IRQ7: P1.B21 (GP50), U7.23 ((INT7*)IRQB)
/JAB1: U7.70 (JAB1), U9.43 (P1.0)
/JAB2: U7.61 (JAB2), U9.44 (P1.1)
/JACX: U7.68 (JACX), U9.45 (P1.2)
/JACY: U7.63 (JACY), U9.46 (P1.3)
/KBCLK: P1.A12 (GP91), R41.1, U9.35 (P0.5)
/KBDATA: P1.A14 (GP93), R42.1, U9.37 (P0.3)
/LAN_RX+: J4.3 (RD+), P1.A54 (LAN_RX+), R2.2
/LAN_RX-: J4.6 (RD-), P1.A52 (LAN_RX-), R1.2
/LAN_TX+: J4.2 (TD-), P1.A53 (LAN_TX+), R3.2
/LAN_TX-: J4.1 (TD+), P1.A51 (LAN_TX-), R4.2
/LINKACT: P1.B59 (GP12), R5.1
/MIDI_AUDIO_L: C57.2, R36.1, R44.2
/MIDI_AUDIO_R: C56.2, R37.1, R45.2
/MIDI_OUT: R60.1, U7.60 (MIDOUT)
/MSCLK: P1.A13 (GP92), R39.1, U9.13 (P3.7)
/MSDATA: P1.A15 (GP94), R40.1, U9.14 (P4.3)
/PE0_CLK+: J4#2.13 (REFCLK+), P1.A47 (PE0_CLK+)
/PE0_CLK-: J4#2.11 (REFCLK-), P1.A45 (PE0_CLK-)
/PE0_RX+: J4#2.33 (PETp0), P1.A43 (PE0_RX+)
/PE0_RX-: J4#2.31 (PETn0), P1.A41 (PE0_RX-)
/PE0_TX+: J4#2.25 (PERp0), P1.A44 (PE0_TX+)
/PE0_TX-: J4#2.23 (PERn0), P1.A42 (PE0_TX-)
/PI_SCL: J7.5 (BCM3/SCL), J11.3 (SCL)
/PI_SDA: J7.3 (BCM2/SDA), J11.4 (SDA)
/PWM1: P3.4 (PWM), U10.5 (PWM1)
/PWM_CLICK: R21.1, U3.8 (PCINT5/OC1B/PA5)
/PWM_GREEN: R23.1, U3.10 (PCINT3/PA3)
/PWM_HDD: R17.1, U3.12 (PCINT1/PA1)
/PWM_PWR: R14.1, U3.13 (PCINT0/PA0)
/PWM_RED: R22.1, U3.11 (PCINT2/PA2)
/PWR_LED+: J3#2.12, R19.2
/PWR_LED-: J3#2.11, Q2.3 (C)
/PWR_SW: SW1.2 (B), U1.1 (IN)
/RI1: P1.A6 (GP03), U5.18 (TTL_OUT2)
/ROM_SW: J7.13 (BCM27), SW4.2 (B)
/RSTDRV: U7.90 (RESDRV), U8.4
/RST_SW: R8.2, R9.2, SW2.2 (B)
/RS_CTS1: J10.8, U5.8 (RS_IN5)
/RS_DCD1: J10.1, U5.4 (RS_IN1)
/RS_DSR1: J10.6, U5.7 (RS_IN4)
/RS_DTR1: J10.4, U5.11 (RS_OUT3)
/RS_RI1: J10.9, U5.5 (RS_IN2)
/RS_RTS1: J10.7, U5.10 (RS_OUT2)
/RS_RX1: J10.2, U5.6 (RS_IN3)
/RS_TX1: J10.3, U5.9 (RS_OUT1)
/RTS1: P1.A5 (GP02), U5.13 (TTL_IN2)
/RX1: D3.1 (K), P1.A7 (GP04), U5.17 (TTL_OUT3)
/RX2: J12.16 (TX/GPIO1), P1.B63 (GP16), U3.2 (PB0/PCINT8)
/SD_CD: J9.9 (CD), P1.A63 (GP86), R53.2
/SD_CLK: P1.A60 (GP83), R50.2
/SD_CMD: P1.A59 (GP82), R49.2, U3.5 (PB2/PCINT10/INT0/OC0A)
/SD_DAT0: P1.A61 (GP84), R51.2, U3.6 (PA7/PCINT7/OC0B)
/SD_DAT1: P1.A62 (GP85), R52.2
/SD_DAT2: P1.A57 (GP80), R47.2
/SD_DAT3: P1.A58 (GP81), R48.2
/SPDIF_OUT: U6.2, U7.67 (JBCX*/SDOUT)
/SPKR: P1.B58 (GP11), R20.1, R38.1
/SYNTH_SW: J7.11 (BCM17), SW3.2 (B)
/TACH1: P3.3 (TACH), R46.2, U10.6 (TACH1)
/TX1: D2.1 (K), P1.A4 (GP01), U5.14 (TTL_IN1)
/TX2: J12.15 (RX/GPIO3), P1.B61 (GP14), U3.3 (PB1/PCINT9)
/USBD1+: L1.3, P1.A23 (USBD1+)
/USBD1-: L1.2, P1.A21 (USBD1-)
/USBD2+: L2.3, P1.A24 (USBD2+)
/USBD2-: L2.2, P1.A22 (USBD2-)
/USBDX1+: J3.3 (D1+), L1.4
/USBDX1-: J3.2 (D1-), L1.1
/USBDX2+: J3.7 (D2+), L2.4
/USBDX2-: J3.6 (D2-), L2.1
/USBHID1+: L3.4, U9.29 (P5.5/HP)
/USBHID1-: L3.1, U9.30 (P5.4/HM)
/USBHID2+: L4.4, U9.31 (P5.1/DP)
/USBHID2-: L4.1, U9.32 (P5.0/DM)
/USBHIDX1+: J2.3 (D1+), L3.3
/USBHIDX1-: J2.2 (D1-), L3.2
/USBHIDX2+: J2.7 (D2+), L4.3
/USBHIDX2-: J2.6 (D2-), L4.2
/V86_SCL: P1.B62 (GP15), R18.1, U3.9 (PCINT4/SCL/PA4), U10.2 (SMCLK)
/V86_SDA: P1.B60 (GP13), R16.1, U3.7 (PA6/PCINT6/OCA1A/SDA), U10.1 (SMDATA)
/VBATT: BT1.1 (+), P1.A55 (VBATT)
/VBUS: C3.2, J1.A4/B9 (VBUS), J1.A9/B4 (VBUS), Q1.3 (S), R10.2, U1.6 (VCC)
/X_SD_CLK: J9.5 (CLK), R50.1
/X_SD_CMD: J9.3 (CMD), R49.1, R56.2
/X_SD_DAT0: J9.7 (DAT0), R51.1, R55.2
/X_SD_DAT1: J9.8 (DAT1), R52.1, R54.2
/X_SD_DAT2: J9.1 (DAT2), R47.1, R58.2
/X_SD_DAT3: J9.2 (DAT3/CD), R48.1, R57.2
/~BRESET: J8.4, U7.15 (~BRESET)
/~DACK1: P1.B28 (GP57), U7.56 (~DACKB(~DACK1*))
/~FM_CS: J8.13, U7.9 (~SCS/~UP)
/~FM_RD: J8.14, U7.10 (~XIOR)
/~FM_WR: J8.15, U7.11 (~XIOW)
/~IOR: P1.B40 (GP31), U7.37 (~IOR)
/~IOW: P1.B39 (GP30), U7.38 (~IOW)
/~PCIRST: J4#2.22 (~PERST), P1.A46 (~PCIRST), U8.2
/~RST_SW: C5.1, J3#2.3, P1.A48 (~RESET), R9.1
GND: BT1.2 (-), C1.2, C2.2, C3.1, C4.2, C5.2, C6.2, C7.2, C8.2, C9.2, C10.2, C11.2, C13.2, C14.2, C15.2, C16.2, C17.1, C19.1, C20.2, C21.2, C22.2, C23.2, C24.1, C25.1, C26.1, C27.1, C28.1, C29.1, C30.2, C31.2, C32.2, C33.1, C34.1, C35.2, C36.2, C37.1, C38.2, C39.1, C40.2, C41.2, C42.2, C43.2, C44.2, C45.2, C47.2, C52.2, C55.2, C56.1, C57.1, C58.2, C59.2, C60.2, C61.1, C63.2, C64.2, C65.1, C66.2, C67.1, C68.2, C69.2, C70.2, C71.2, C72.2, C73.2, C74.2, C75.2, C76.2, D1.1 (K), H1.1, H2.1, H3.1, H4.1, J1.A1/B12 (GND), J1.A12/B1 (GND), J1.S (SHIELD), J2.4 (GND1), J2.8 (GND2), J2.S (Shield), J3.4 (GND1), J3.8 (GND2), J3.S (Shield), J3#2.4, J3#2.5, J3#2.8, J3#2.9, J4.8 (C1), J4.10 (D2), J4.CASE@1, J4.CASE@2, J4#2.4 (GND), J4#2.9 (GND), J4#2.15 (GND), J4#2.18 (GND), J4#2.21 (GND), J4#2.26 (GND), J4#2.27 (GND), J4#2.29 (GND), J4#2.34 (GND), J4#2.35 (GND), J4#2.37 (GND), J4#2.40 (GND), J4#2.43 (GND), J4#2.50 (GND), J4#2.S1 (SHIELD), J4#2.S2 (SHIELD), J5.3 (GND), J6.S, J7.6 (GND), J7.9 (GND), J7.14 (GND), J7.20 (GND), J7.25 (GND), J7.30 (GND), J7.34 (GND), J7.39 (GND), J8.3, J8.20, J9.6 (VSS), J9.S (Shield), J10.5, J10.10 (GND), J10.11 (GND), J11.1 (GND), J12.10 (GND), JP5.1, P1.A2 (GND), P1.A19 (GND), P1.A20 (GND), P1.A25 (AGND), P1.A26 (AGND), P1.A35 (GND), P1.A36 (GND), P1.A49 (GND), P1.A50 (GND), P1.A64 (GP87), P1.B19 (GND), P1.B20 (GND), P1.B37 (GND), P1.B38 (GND), P1.B55 (GND), P1.B56 (GND), P3.1 (GND), Q2.2 (E), Q3.2 (E), Q4.2 (E), Q5.2 (E), Q6.2 (E), Q7.2 (E), R6.2, R7.2, R33.2, R34.2, R35.2, R59.2, SW1.1 (A), SW2.1 (A), SW3.1 (A), SW4.1 (A), SW5.2 (B), SW6.2 (B), U1.2 (GND), U1.3 (CLEAR), U2.1 (GND), U3.14 (GND), U4.2 (GND), U5.25 (GND), U6.3 (GND), U7.18 (SGND1), U7.46 (DGND1), U7.53 (SGND4), U7.66 (SGND2), U7.71 (TEST), U7.80 (AGND), U7.97 (SGND3), U8.3 (GND), U9.18 (GND), U10.9 (CLK), U10.13 (GND), U11.3 (CPGND), U11.9 (AGND), U11.10 (DEMP), U11.11 (FLT), U11.12 (SCK), U11.16 (FMT), U11.19 (DGND), U12.2 (GND), U13.2 (GND)
unnamed: C1.1, R1.1, R2.1
unnamed: C2.1, R3.1, R4.1
unnamed: C46.2, C52.1, R33.1, R38.2
unnamed: C48.2, J6.R
unnamed: C49.2, J6.T
unnamed: C50.2, R34.1, R36.2
unnamed: C51.2, R35.1, R37.2
unnamed: D1.2 (A), R15.2
unnamed: D2.2 (A), R24.2
unnamed: D3.2 (A), R25.2
unnamed: D4.2 (A), JP3.2, SP1.2
unnamed: D5.2 (A), JP4.2, SP2.2
unnamed: D6.3 (GK), R29.2
unnamed: D6.1 (RK), R28.2
unnamed: J1.A5 (CC1), R7.1
unnamed: J1.B5 (CC2), R6.1
unnamed: J4.9 (D1), R11.2
unnamed: J4.11 (D4), R5.2
unnamed: J4#2.20 (~W_DISABLE), R32.1
unnamed: JP3.1, R26.2
unnamed: JP3.3, R30.2
unnamed: JP4.1, R27.2
unnamed: JP4.3, R31.2
unnamed: C31.1, F1.2, J3.1 (VBUS1)
unnamed: C35.1, F3.2, J3.5 (VBUS2)
unnamed: C32.1, F2.2, J2.1 (VBUS1)
unnamed: C36.1, F4.2, J2.5 (VBUS2)
unnamed: J5.1 (VIN), U6.4
unnamed: C68.1, J12.9 (5V), JP2.1
unnamed: J12.12 (D3/GPIO0), SW5.1 (A)
unnamed: Q1.1 (G), R10.1, U1.4 (~OUT)
unnamed: Q2.1 (B), R14.2
unnamed: Q3.1 (B), R17.2
unnamed: Q4.1 (B), R20.2
unnamed: C20.1, Q4.3 (C), R26.1, R30.1
unnamed: Q5.1 (B), R21.2
unnamed: C21.1, Q5.3 (C), R27.1, R31.1
unnamed: Q6.1 (B), R22.2
unnamed: Q6.3 (C), R28.1
unnamed: Q7.1 (B), R23.2
unnamed: Q7.3 (C), R29.1
unnamed: SW6.1 (A), U9.16 (P4.6)
unnamed: R12.1, U3.4 (PB3/PCINT11/~RESET)
unnamed: C15.1, U4.4 (BYP)
unnamed: C12.1, U5.28 (C1+)
unnamed: C12.2, U5.24 (C1-)
unnamed: C18.1, U5.1 (C2+)
unnamed: C18.2, U5.2 (C2-)
unnamed: C13.1, U5.27 (V+)
unnamed: C19.2, U5.3 (V-)
unnamed: R15.1, U5.21 (~INVALID)
unnamed: C50.1, U7.75 (LAUX1)
unnamed: C43.1, U7.77 (LFILT)
unnamed: C53.1, U7.87 (LLINE)
unnamed: C45.1, C49.1, U7.73 (LOUT)
unnamed: C46.1, U7.88 (MIN)
unnamed: C51.1, U7.74 (RAUX1)
unnamed: C40.1, C41.1, U7.79 (REFFLT)
unnamed: C42.1, U7.76 (RFILT)
unnamed: C54.1, U7.86 (RLINE)
unnamed: C47.1, C48.1, U7.72 (ROUT)
unnamed: C34.2, U7.100 (XTALI), X1.2
unnamed: C33.2, U7.99 (XTALO), X1.1
unnamed: C39.2, U9.42 (VDD33)
unnamed: R43.1, U10.4 (ADDR_SEL)
unnamed: C62.2, U11.4 (CAPM)
unnamed: C62.1, U11.2 (CAPP)
unnamed: C65.2, C67.2, U11.18 (LDOO)
unnamed: R44.1, U11.6 (OUTL)
unnamed: R45.1, U11.7 (OUTR)
unnamed: C61.2, U11.5 (VNEG)
unnamed: C73.1, U12.4 (BYP)
unnamed: C74.1, U13.4 (BYP)
VCC: C4.1, C8.1, C9.1, C10.1, C11.1, C14.1, C24.2, C30.1, C70.1, C71.1, C72.1, D4.1 (K), D5.1 (K), D6.2 (A), F1.1, F3.1, FB1.1, FB2.1, J5.2 (VCC), J7.2 (5v), J7.4 (5v), J8.17, J11.2 (VCC), JP1.2, JP2.2, P1.B1 (VCC), P1.B2 (VCC), P3.2 (VDD), Q1.2 (D), R8.1, R13.1, R19.1, SP1.1, SP2.1, U2.3 (VIN), U4.1 (IN), U4.3 (EN), U5.22 (~FORCEOFF), U5.23 (FORCEON), U5.26 (VCC), U6.1 (OE), U6.5 (VCC), U12.1 (IN), U12.3 (EN), U13.1 (IN), U13.3 (EN)

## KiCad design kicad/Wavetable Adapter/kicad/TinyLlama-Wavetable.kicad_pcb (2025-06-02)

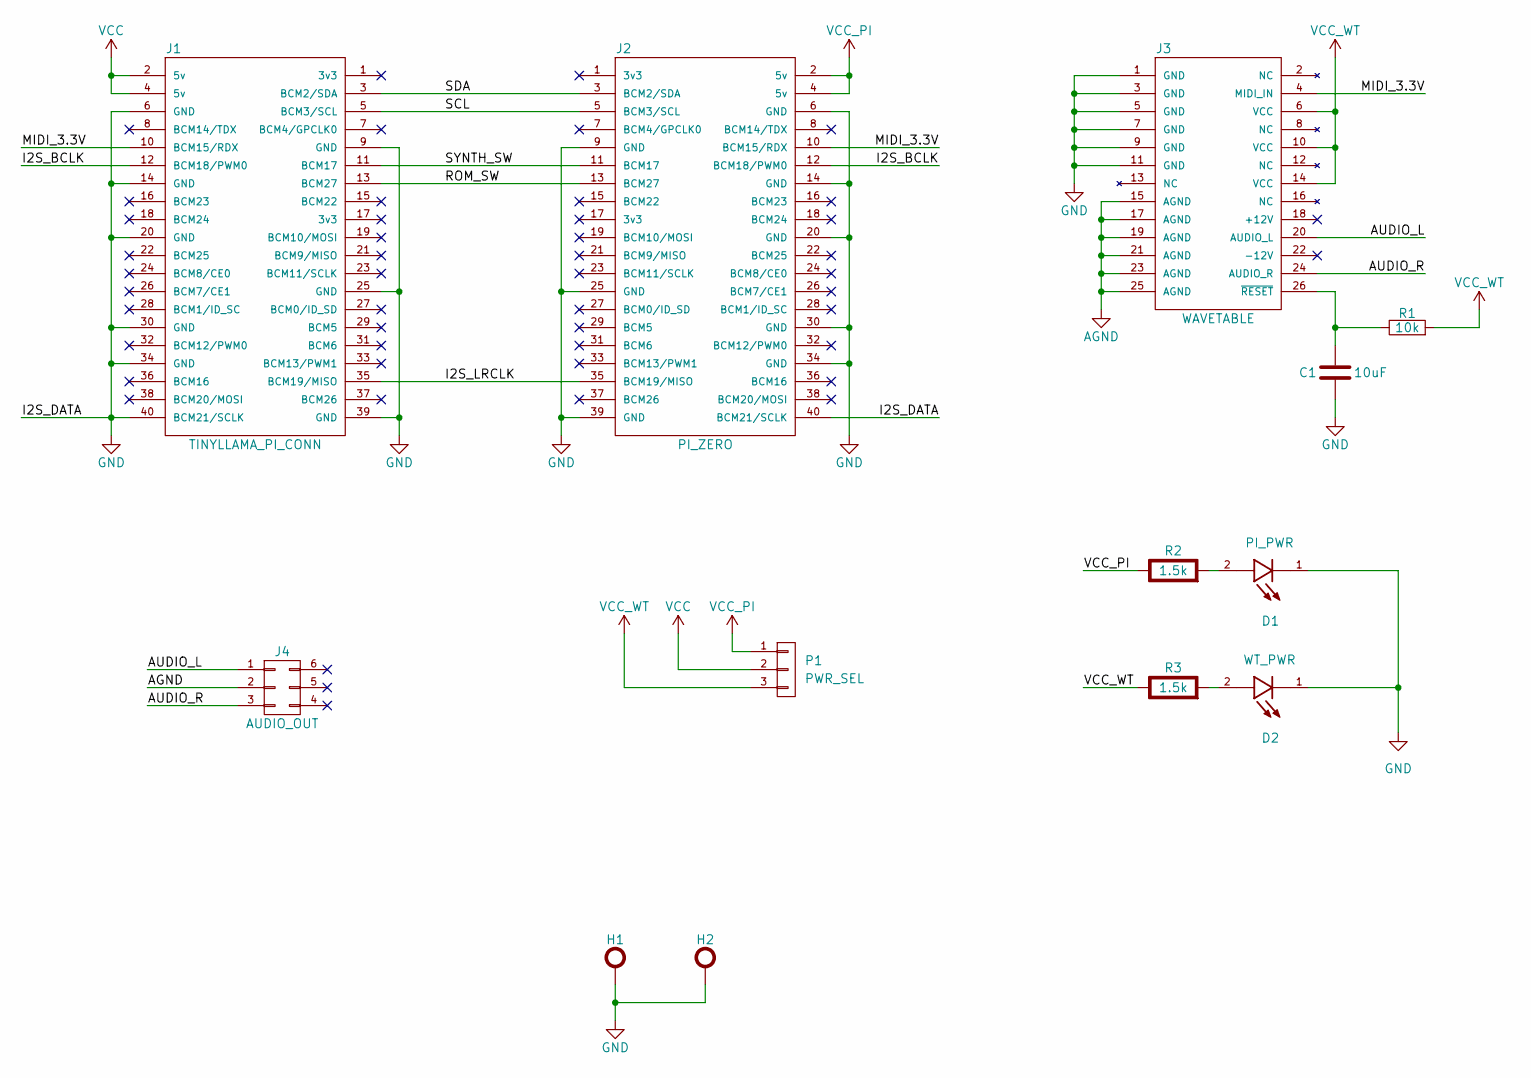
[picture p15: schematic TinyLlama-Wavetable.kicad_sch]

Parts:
C1: 10uF; C_0603_1608Metric
D1: PI_PWR; D_0805_2012Metric; PARTREV D; LCSC C130723
D2: WT_PWR; D_0805_2012Metric; PARTREV D; LCSC C130723
H1, H2: H_HOLE; H_440_HOLE
J1: TINYLLAMA_PI_CONN; J_CONN_RPI_MIRRORED_SMD
J2: PI_ZERO; J_CONN_RPI_SMD
J3: WAVETABLE; J_CONN_WAVETABLE
J4: AUDIO_OUT; P_CONN_02X03_SMD
P1: PWR_SEL; PinHeader_1x03_P2.54mm_Horizontal
R1: 10k; R_0603_1608Metric
R2, R3: 1.5k; R_0603_1608Metric; Rating W

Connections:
/AUDIO_L: J3.20 (AUDIO_L), J4.1
/AUDIO_R: J3.24 (AUDIO_R), J4.3
/I2S_BCLK: J1.12 (BCM18/PWM0), J2.12 (BCM18/PWM0)
/I2S_LRCLK: J1.35 (BCM19/MISO), J2.35 (BCM19/MISO)
/MIDI_3.3V: J1.10 (BCM15/RDX), J2.10 (BCM15/RDX), J3.4 (MIDI_IN)
/ROM_SW: J1.13 (BCM27), J2.13 (BCM27)
/SCL: J1.5 (BCM3/SCL), J2.5 (BCM3/SCL)
/SDA: J1.3 (BCM2/SDA), J2.3 (BCM2/SDA)
/SYNTH_SW: J1.11 (BCM17), J2.11 (BCM17)
AGND: J3.15 (AGND), J3.17 (AGND), J3.19 (AGND), J3.21 (AGND), J3.23 (AGND), J3.25 (AGND), J4.2
GND: C1.2, D1.1, D2.1, H1.1, H2.1, J1.6 (GND), J1.9 (GND), J1.14 (GND), J1.20 (GND), J1.25 (GND), J1.30 (GND), J1.34 (GND), J1.39 (GND), J1.40 (BCM21/SCLK), J2.6 (GND), J2.9 (GND), J2.14 (GND), J2.20 (GND), J2.25 (GND), J2.30 (GND), J2.34 (GND), J2.39 (GND), J2.40 (BCM21/SCLK), J3.1 (GND), J3.3 (GND), J3.5 (GND), J3.7 (GND), J3.9 (GND), J3.11 (GND)
unnamed: C1.1, J3.26 (~RESET), R1.1
unnamed: D1.2, R2.2 (-)
unnamed: D2.2, R3.2 (-)
VCC: J1.2 (5v), J1.4 (5v), P1.2
VCC_PI: J2.2 (5v), J2.4 (5v), P1.1, R2.1 (+)
VCC_WT: J3.6 (VCC), J3.10 (VCC), J3.14 (VCC), P1.3, R1.2, R3.1 (+)

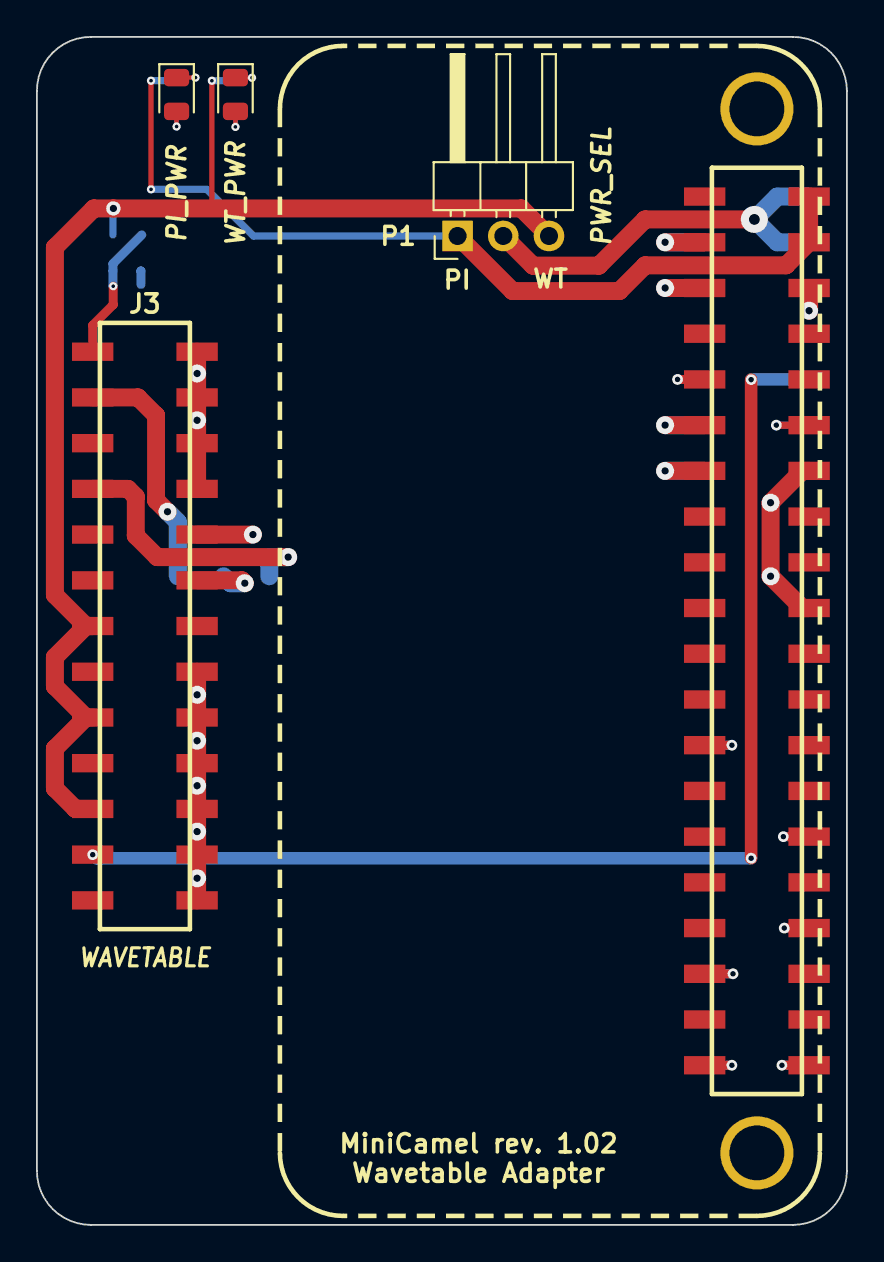
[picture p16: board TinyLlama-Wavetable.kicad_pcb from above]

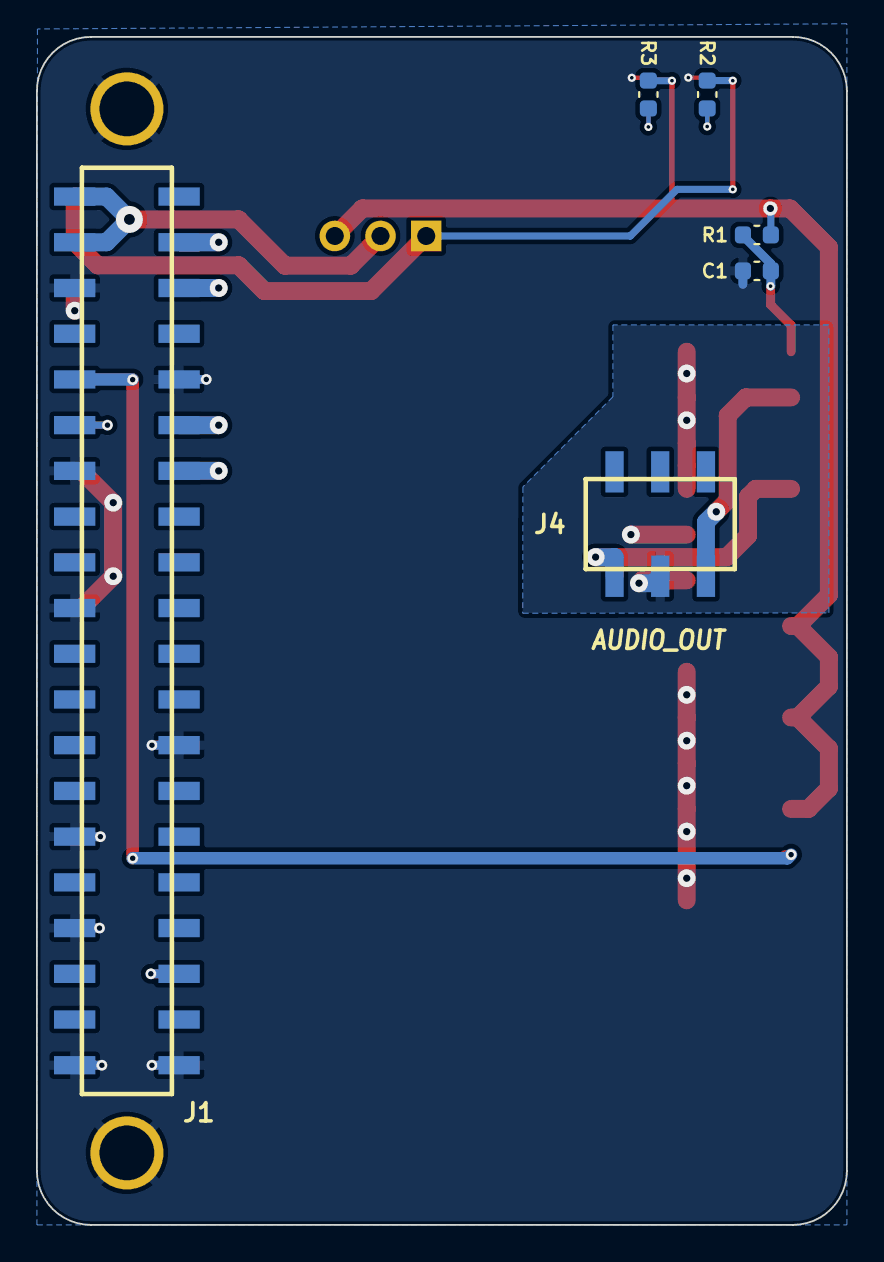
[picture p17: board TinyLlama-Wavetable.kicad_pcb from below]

Board: 2 copper layers, 45.0 x 66.0 mm, 13 parts (6 on the bottom side), 17 nets.

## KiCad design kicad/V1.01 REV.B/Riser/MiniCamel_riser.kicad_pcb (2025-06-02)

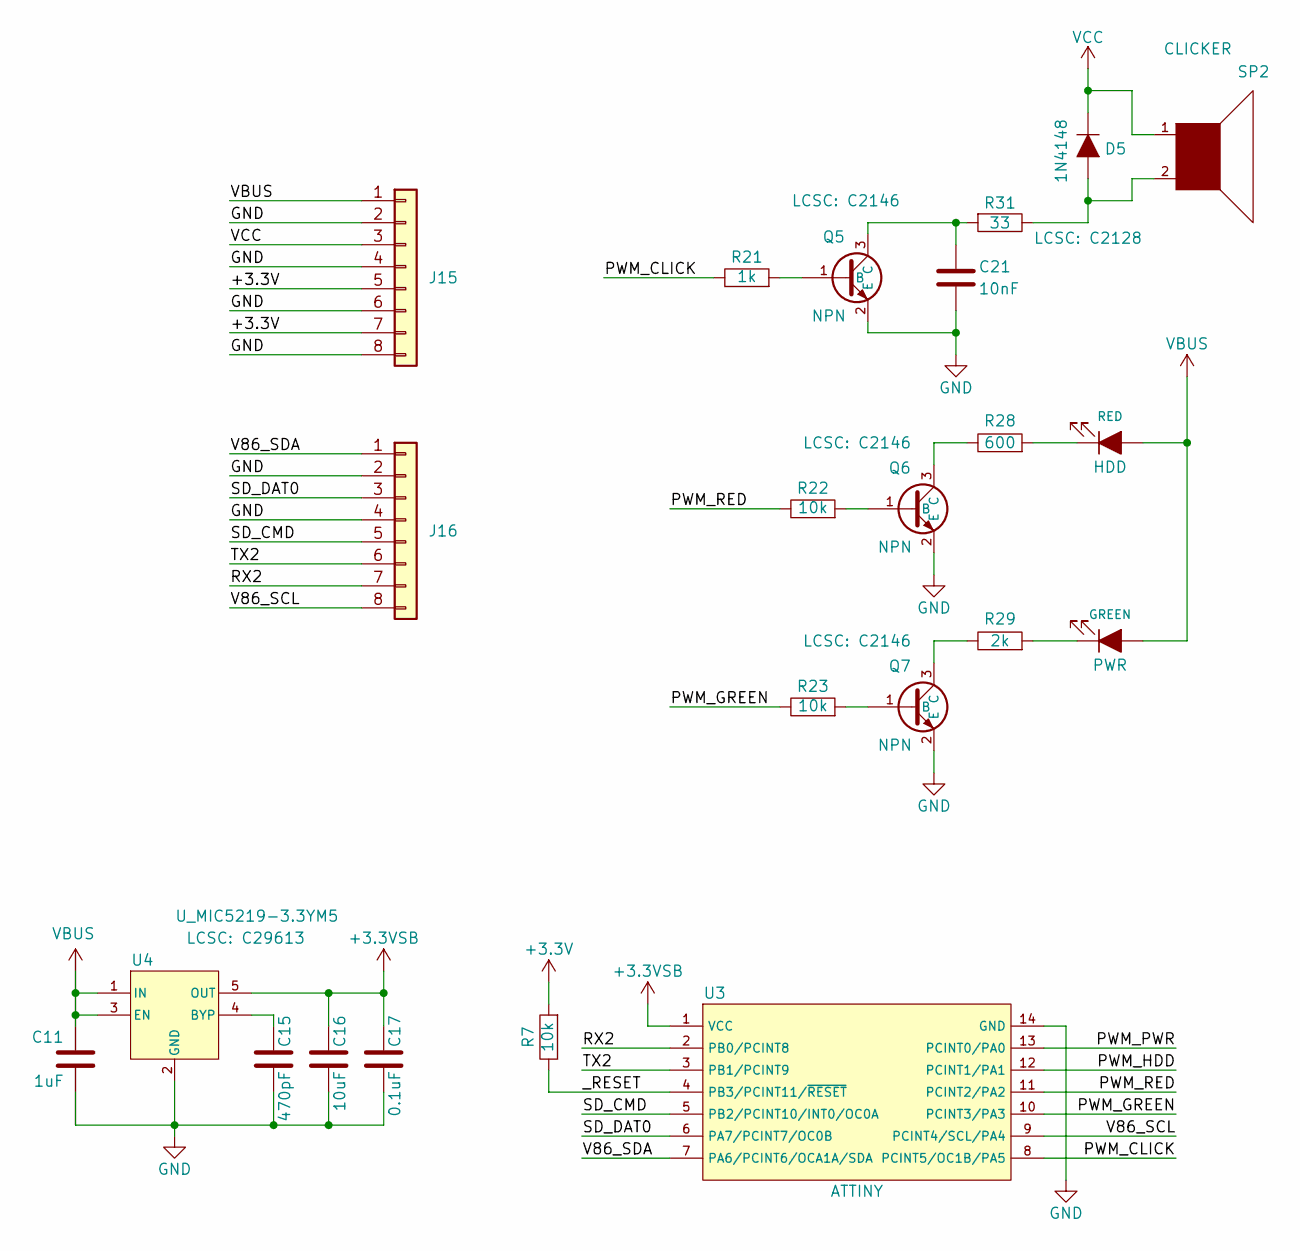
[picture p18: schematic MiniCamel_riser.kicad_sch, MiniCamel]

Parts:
C11: 1uF; C_0603_1608Metric; LCSC C207017
C15: 470pF; C_0603_1608Metric; LCSC C207017
C16: 10uF; C_0603_1608Metric; LCSC C207017
C17: 0.1uF; C_0603_1608Metric; LCSC C207017
C21: 10nF; C_0603_1608Metric; LCSC C207017
D5: 1N4148; D_SOD-323F; LCSC C2128
D6: PWR; LED_LTST-S220KSKT; PARTREV D; LCSC C130723
D7: HDD; LED_LTST-S220KSKT; PARTREV D; LCSC C130723
J15, J16: Conn_01x06; PinHeader_1x08_P2.54mm_Vertical_no_outline
Q5, Q6, Q7: NPN; Q_BJT_SOT-23-3; LCSC C2146
R7, R22, R23: 10k; R_0603_1608Metric; LCSC C207017
R21: 1k; R_0603_1608Metric; LCSC C207017
R28: 600; R_0603_1608Metric; LCSC C207017
R29: 2k; R_0603_1608Metric; LCSC C207017
R31: 33; R_0603_1608Metric; LCSC C207017
SP2: CLICKER; XDCR_SMT-0927-S-12-R; PARTREV 1/19/2017; LCSC C252917
U3: ATTINY; SOIC-14_3.9x8.7mm_P1.27mm
U4: U_MIC5219-3.3YM5; U_SOT-23-5; LCSC C29613

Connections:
+3.3V: J15.5, J15.7, R7.2
+3.3VSB: C16.1, C17.2, U3.1 (VCC), U4.5 (OUT)
/PWM_CLICK: R21.1, U3.8 (PCINT5/OC1B/PA5)
/PWM_GREEN: R23.1, U3.10 (PCINT3/PA3)
/PWM_HDD: U3.12 (PCINT1/PA1)
/PWM_PWR: U3.13 (PCINT0/PA0)
/PWM_RED: R22.1, U3.11 (PCINT2/PA2)
/RX2: J16.7, U3.2 (PB0/PCINT8)
/SD_CMD: J16.5, U3.5 (PB2/PCINT10/INT0/OC0A)
/SD_DAT0: J16.3, U3.6 (PA7/PCINT7/OC0B)
/TX2: J16.6, U3.3 (PB1/PCINT9)
/V86_SCL: J16.8, U3.9 (PCINT4/SCL/PA4)
/V86_SDA: J16.1, U3.7 (PA6/PCINT6/OCA1A/SDA)
/_RESET: R7.1, U3.4 (PB3/PCINT11/~RESET)
GND: C11.2, C15.2, C16.2, C17.1, C21.2, J15.2, J15.4, J15.6, J15.8, J16.2, J16.4, Q5.2 (E), Q6.2 (E), Q7.2 (E), U3.14 (GND), U4.2 (GND)
unnamed: D5.2 (A), R31.1, SP2.2
unnamed: D6.1 (K), R29.2
unnamed: D7.1 (K), R28.2
unnamed: Q5.1 (B), R21.2
unnamed: C21.1, Q5.3 (C), R31.2
unnamed: Q6.1 (B), R22.2
unnamed: Q6.3 (C), R28.1
unnamed: Q7.1 (B), R23.2
unnamed: Q7.3 (C), R29.1
unnamed: C15.1, U4.4 (BYP)
VBUS: C11.1, D6.2 (A), D7.2 (A), J15.1, U4.1 (IN), U4.3 (EN)
VCC: D5.1 (K), J15.3, SP2.1

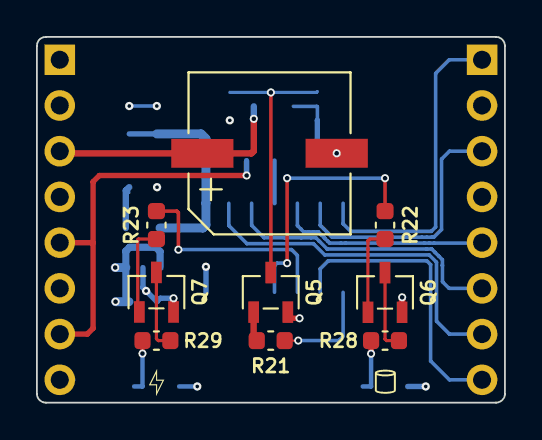
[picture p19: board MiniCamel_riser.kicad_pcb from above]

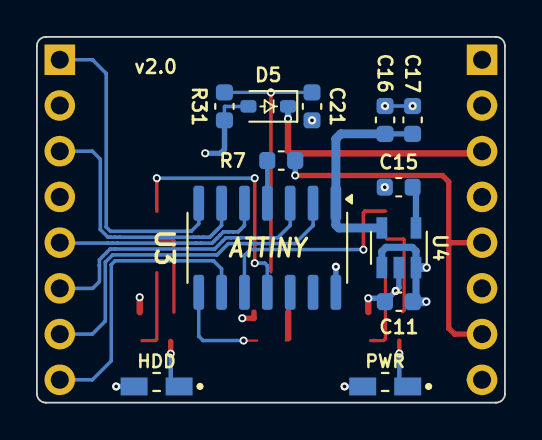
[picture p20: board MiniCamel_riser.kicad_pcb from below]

Board: 4 copper layers, 26.0 x 20.3 mm, 23 parts (14 on the bottom side), 25 nets.

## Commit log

2024-06-26 Delete case directory
    will need to create a new case since the board dimensions are different
    [case_bottom.step, case_top.step, case_top_button.step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]
2024-06-26 Delete kicad directory
    will upload
    [2041119-1.stp, JackPJ313D.STEP, TF-01A--3DModel-STEP-56544.STEP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]
2024-06-26 Create kicad
2025-06-05 250605-01
    updated revision numbers on schematic
    [MiniCamel_V1.01.kicad_sch, opl3module-BOM.xlsx, opl3module.kicad_pcb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]
